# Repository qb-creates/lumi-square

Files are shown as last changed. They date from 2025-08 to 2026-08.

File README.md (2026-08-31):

# LumiSquare
LumiSquare is a handheld 4x4 LED button game console built around an ATSAMD21J18A. Each of the sixteen silicone pads sits on top of its own RGB LED, and a single 16-channel constant-current driver paints all forty-eight color channels through a column-multiplexed matrix. The console ships with three games, spoken score readout through a DFPlayer Mini, a tone buzzer for note feedback, and a USB-C rechargeable power path that lets the device be played while it charges.

- Project Video (YouTube): https://youtu.be/QTP0zEY1d-M?si=SdRo0hkOKRWzujol
- Multiplexed Display: https://en.wikipedia.org/wiki/Multiplexed_display
- Keyboard Matrix Circuit (diode anti-ghosting): https://en.wikipedia.org/wiki/Keyboard_matrix_circuit
- STP16CPC05 Constant Current LED Driver: https://www.st.com/en/power-management/stp16cpc05.html
- DFPlayer Mini Documentation: https://wiki.dfrobot.com/DFPlayer_Mini_SKU_DFR0299

<div align="center">
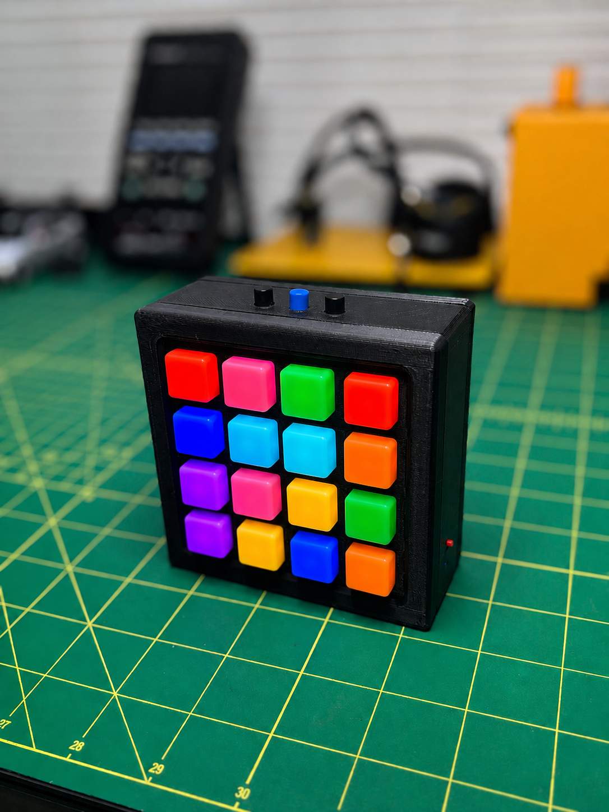
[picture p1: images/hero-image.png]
LumiSquare
	
</div>

## Table of Contents
1. [Software Used](#software)
2. [Main Control Board Circuit](#maincontrolboard)
    - [Power Path and Battery Charging](#powerpath)
    - [LED Button Matrix Driver](#leddriver)
    - [Button Matrix Circuit](#buttonmatrixcircuit)
    - [Buzzer Control](#buzzercontrol)
    - [DF Player Mini](#dfplayer)
    - [Game Firmware](#gamefirmware)
        - [Simon](#simon)
        - [Memory Matching](#memorymatching)
        - [Light Dash](#lightdash)
    - [Power Consumption](#powerconsumption)
    - [Charging Notes](#charging)
    - [Parts List](#partslist)
    - [Schematics](#schematics)
    - [PCB Images](#pcbimages)
3. [Pin Mapping](#pinmapping)
    - [DF Player Mini](#dfplayerpins)
    - [Buzzer](#buzzerpins)
    - [LED Mapping](#ledmapping)
    - [4x4 Button Mapping](#buttonmapping)
4. [STL Viewer](#stlviewer)
    - [Full Design](#fulldesign)
    - [Face Plate](#faceplate)
    - [Back Cover](#backcover)
    - [Main Body](#mainbody)
    - [Main Control Board](#maincontrolboardstl)

## 1. Software Used
- VSCode: https://code.visualstudio.com
- OpenOCD (Arm GDB Bridge): https://openocd.org/pages/about.html
- Arm GNU Toolchain (programming and debugging): https://developer.arm.com/tools-and-software/gnu-toolchain
- KiCad (PCB Design): https://www.kicad.org
- Autodesk Fusion (Parts Design): https://www.autodesk.com/products/fusion-360/overview

The firmware is a CMake project with two presets. `cmake_generate_debug` / `cmake_build_debug` cross compile for the SAMD21 with `arm-none-eabi-gcc` (Cortex-M0+, `F_CPU=48000000`) and emit an `.elf`, `.hex`, and `.bin`. `cmake_generate_desktop` / `cmake_build_desktop` build the same game code as a desktop executable with `DESKTOP_SIMULATION` defined, which swaps the SAMD21 hardware layer for an ImGui/GLFW/miniaudio implementation so the games, LED colors, and audio can be developed without the board. Flashing and debugging is done over the Samtec FTSH-105 SWD header using OpenOCD as the GDB bridge for `arm-none-eabi-gdb`.

## 2. Main Control Board Circuit
The main control board carries everything except the switches and LEDs themselves: the USB-C charger, the battery power path, both boost converters, the 3.3 V regulator, the SAMD21, the LED driver and its column drivers, the tone buzzer, and the DFPlayer Mini. It connects to the button matrix board through two 12-pin headers, one carrying the twelve LED cathode channels and one carrying the four button rows, four button columns, and four LED column anodes.

<div align="center">
 <table>
     <tr>
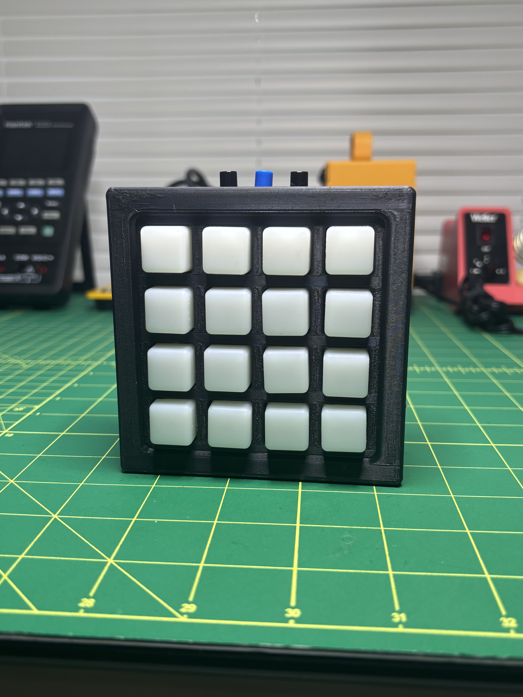
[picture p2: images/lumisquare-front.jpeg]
LumiSquare Front
         <td></td>
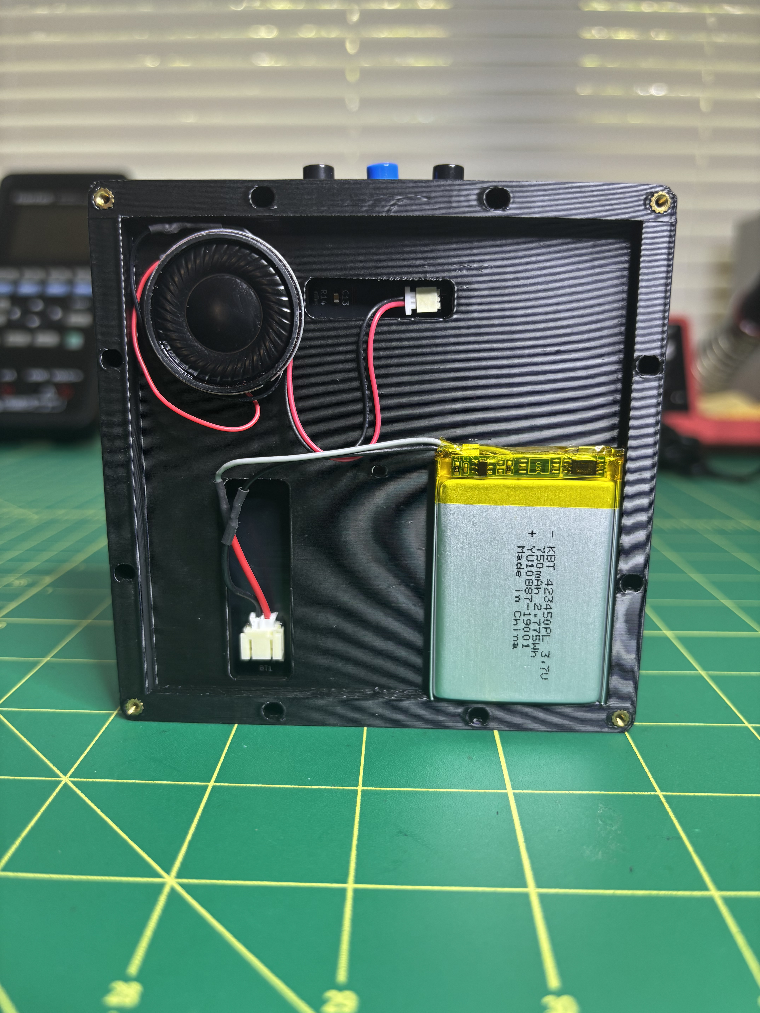
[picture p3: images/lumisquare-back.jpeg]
LumiSquare Back
         <td></td>
     </tr>
     <tr>
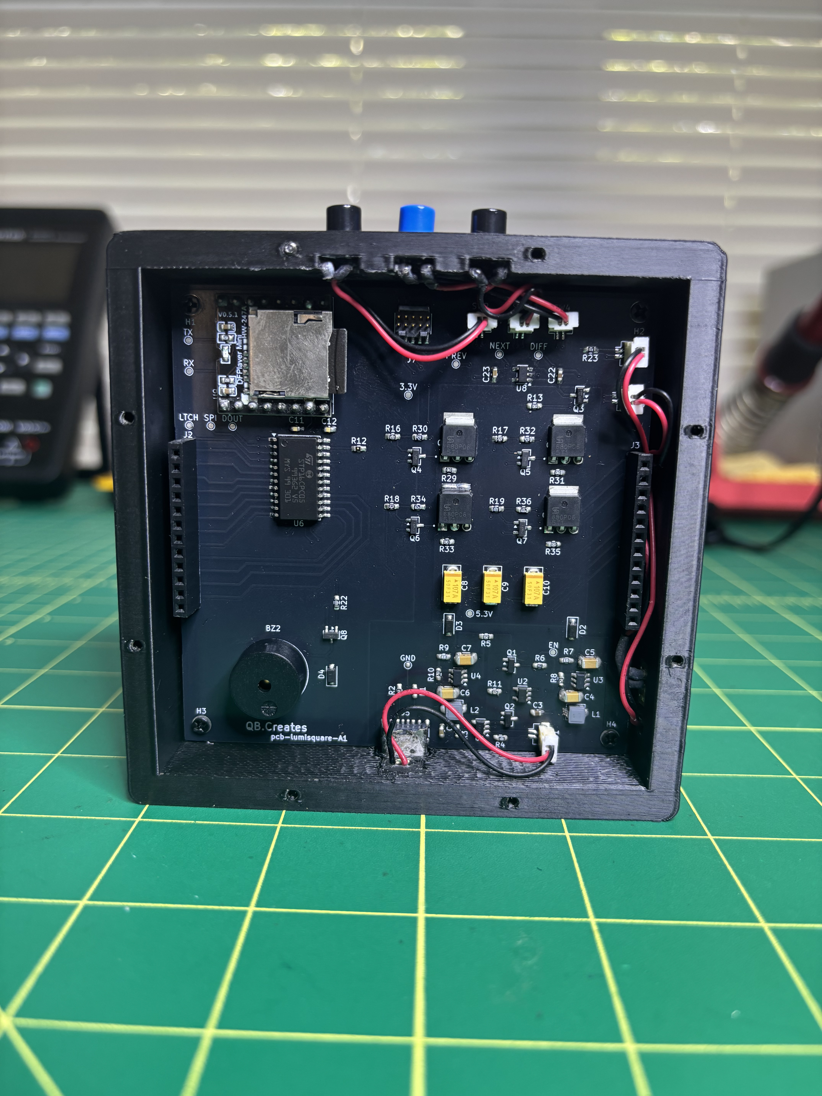
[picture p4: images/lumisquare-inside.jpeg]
LumiSquare Inside
         <td></td>
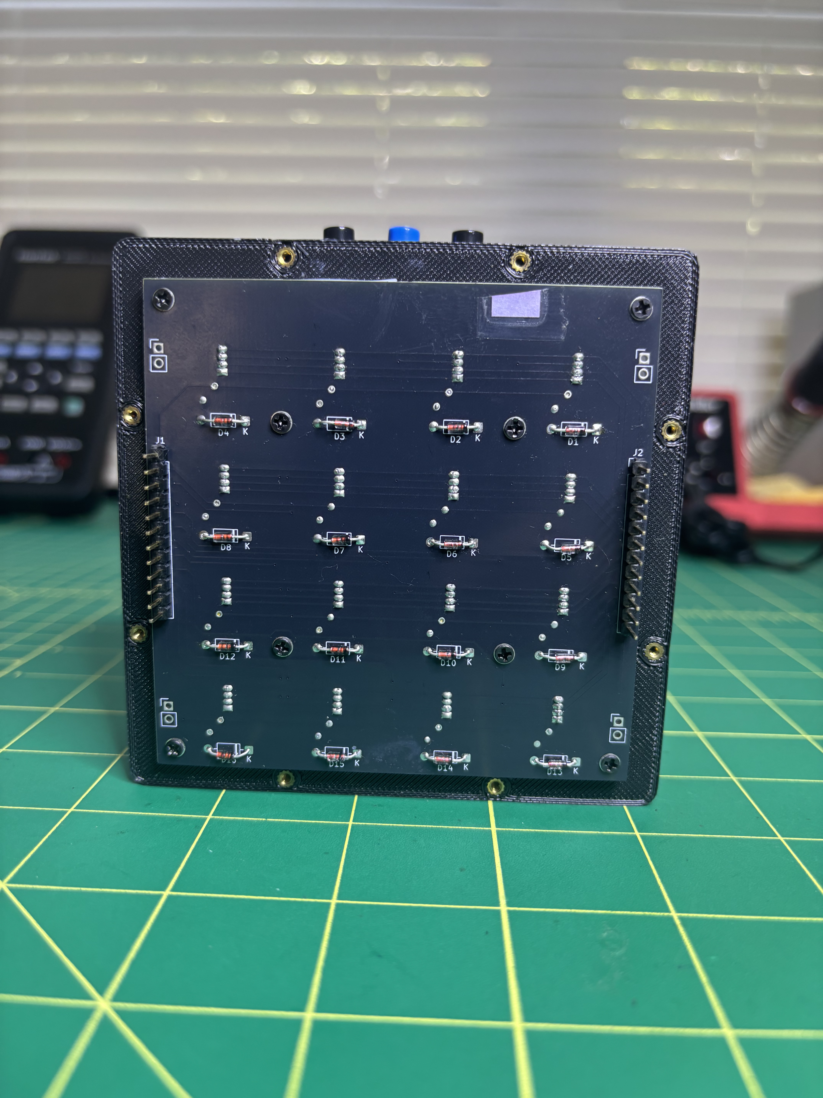
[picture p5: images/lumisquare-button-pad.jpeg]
LumiSquare Button Pad
         <td></td>
     </tr>
 </table>
</div>

### Power Path and Battery Charging
The board runs from either a single cell LiPo or USB-C, and the two sources are kept electrically separate so the device can be used while it charges.

Charging is handled by an MCP73831-2-OT (U1) off the USB-C VBUS rail. The USB-C receptacle is a power-only 6-pin part with the two 5.1k CC pulldowns (R1, R2) needed to advertise a sink. The charge current is set by the PROG resistor:

- Charge current = 1000 V / R3 = 1000 V / 10 kohm = 100 mA

A status LED (D1) with a 330 ohm series resistor (R4) is driven from the STAT pin.

The power path itself is built from two TLV61070A boost converters and a P-channel pass device:

- Q2 (IRLML2246) sits between the battery and the battery-side boost converter. Its gate is tied to the 5 V USB rail and pulled to ground through R11 (220k). With no USB present the gate sits at 0 V and the MOSFET conducts; when USB is plugged in the gate is pulled to 5 V and the battery is disconnected from the system load.
- U3 (TLV61070A) is the battery boost converter. Its enable pin is pulled up to the battery through R6 (150k) and is gated two ways: a TPS3840 (U2) supervisor pulls it low on battery undervoltage, and Q1 (IRLML6244) pulls it low whenever the 5 V USB rail is present.
- U4 (TLV61070A) is the USB boost converter. Its enable pin is tied to its own input, so it runs whenever USB power is present.
- Both converters use a 4.7uH inductor and the same 720k/80k feedback divider, and their outputs are combined onto the 5.3 V rail through Schottky diodes (D2, D3, 1N5819HW-7-F) with 300uF of bulk capacitance (C8, C9, C10).

Downstream of the 5.3 V rail, SW1 is the system power switch feeding a MIC5225-3.3YM5 (U8) that produces the +3.3 V Main rail for the SAMD21, the DFPlayer Mini, and the buzzer. The 5.3 V rail itself powers the LED column drivers, so the RGB LEDs get their headroom from the boost output rather than the regulated logic rail.

### LED Button Matrix Driver
Sixteen common-anode RGB LEDs are driven as a 4x4 multiplexed matrix. Anodes are shared per column, and cathodes are shared per row and color, which reduces forty-eight LED channels down to twelve driver channels plus four column selects.

The cathode side is an STP16CPC05MTR (U6) constant-current sink. Twelve of its sixteen channels are used, one for each row and color combination, and a 200 ohm resistor (R12) on R-EXT sets the per-channel current for all of them. The MCU talks to it over SERCOM4 in SPI master mode (MSB first, 16 bits per update), with a separate GPIO line used to pulse the latch.

The anode side is a high-side switch per column. Each column select from the MCU drives an MMBT3904 (Q4-Q7) through a 2.2k base resistor with a 47k pulldown; the transistor pulls the gate of a TSM680P06CH P-channel MOSFET (Q15-Q18) down against a 100k pullup to the 5.3 V rail, and the MOSFET drain feeds that column's anode line.

Color depth comes from binary code modulation rather than a per-channel PWM peripheral. Each LED stores its color as eight bit planes in `ledColorData[column][row][plane]`. `refreshLeds()` services one LED per call: it enables that LED's column, then shifts out all eight planes back to back, holding plane *i* for 2^i NOP loops so the planes carry the same weighting as the bits of an 8-bit value. After the last plane the driver is cleared to `0x0000` and the next LED index is selected. Only one column ever sources current at a time, and the sixteen LED slots repeat fast enough that the display looks continuous.

Per-LED intensity is a scale from 0 to 1 applied to the color before the bit planes are rebuilt, so the games can dim a pad (the idle Simon pads sit at 0.2 intensity, for example) without changing its color.

### Button Matrix Circuit
The button matrix board holds the sixteen switches, the sixteen RGB LEDs, and nothing else. Switches are wired as a standard 4x4 matrix with a 1N4148 diode in series with every switch (D1-D16) so that simultaneous presses cannot ghost onto unrelated rows. The MCU drives one column low at a time and reads the four row inputs, which are held high by internal pullups, so a pressed button reads as a logic low on its row while its column is active.

The LEDs on this board are wired to match. Anodes are commoned per column (LED_COL1 through LED_COL4) and cathodes are commoned per row and color (LED_R1/G1/B1 through LED_R4/G4/B4). Both groups leave the board on 12-pin headers that mate with the main control board.

**Assembly notes for the button pad:**

- The 4x4 silicone button pad in the parts list is not the right size for this enclosure. The individual pads have to be cut out of the sheet and placed into the pockets in the face plate.
- If you have the button matrix board fabricated, order it with an immersion gold (ENIG) finish. The exposed contact pads need a gold surface for the conductive pill on the bottom of each silicone button to make reliable contact.
- If the board is made with a plain finish instead, buy the copper tape listed in the parts list and adhere a piece to the bottom of each button pad so that the button can bridge the traces.

### Buzzer Control
Tones are produced by a magnetic transducer (BZ2, RDT-4.000-1375-NS1) switched on the low side by an MMBT3904 (Q8). The base is driven through a 2.2k resistor (R22) from the MCU, and a 1N4148W (D4) across the transducer clamps the inductive kickback back into the +3.3 V rail.

The drive signal is hardware PWM from TC7 on PB23. TC7 runs from the 48 MHz main clock with a divide-by-256 prescaler in match PWM mode:

- Timer clock = 48 MHz / 256 = 187.5 kHz
- Output frequency = 187500 / (CC0 + 1)
- `CC1` is always set to `CC0 / 2`, which holds the duty cycle at 50 percent regardless of pitch

Because the period register alone determines pitch, the `MusicNote` enum stores CC0 values directly instead of frequencies. For example `MusicNote::C4 = 716`, which gives 187500 / 717 = 261.5 Hz. Starting and stopping a note is just enabling or disabling the timer, so note timing stays exact while the game loop is busy elsewhere.

### DF Player Mini
Spoken audio comes from a DFPlayer Mini (DFR0299) running off the +3.3 V rail, with its speaker outputs broken out to a JST connector. The module is driven from SERCOM5 in USART mode on PA20/PA21 at 9600 baud.

Every DFPlayer command is a fixed 10-byte frame (`0x7E 0xFF 0x06 <cmd> 0x00 <param hi> <param lo> <checksum hi> <checksum lo> 0xEF`). Rather than building those frames at runtime, the firmware stores all of them precomputed in a constant table, so playing a clip is a table lookup. Frames are pushed out by DMAC channel 0 triggered off the SERCOM5 transmit event, one beat per trigger, so the game loop never blocks on the UART.

Replies come back through the SERCOM5 receive interrupt, which buffers the module's 20-byte response (the command acknowledgement plus the playback-finished frame) and fires a completion callback when the terminating `0xEF` arrives. That callback is what advances queued voice-over sequences, which is how the console reads a multi-digit score back as separate clips.

Audio content is organized into four folders on the SD card, and the command table plays from them by folder and track number:

| Folder | Contents |
|:--|:--|
| 01 | Digits 0 through 9 |
| 02 | 10 through 20, then 30, 40, 50, 60, 70, 80, 90 |
| 03 | 100, 200, 300, 400, 500 |
| 04 | Phrases: "your score is", "new high score", the game names, the difficulty names, countdown, mute, unmute |

To read a score such as 342, the firmware queues the hundreds clip, then the tens clip, then the ones clip, and lets the completion callback chain them together. Volume is set with command `0x06`; the unmute command sends a value of 25, and muting sends a value of 0.

### Game Firmware
The firmware is a fixed-timestep game engine. TC3 runs from the 48 MHz clock with a divide-by-1024 prescaler and is preloaded so it overflows every 16 ms, giving a 62.5 Hz update rate. The main loop looks like this:

```cpp
while (true)
{
    LEDMatrix::refreshLeds();

    if (!DeviceUtility::fixedUpdate)
        continue;

    DeviceUtility::fixedUpdate = false;
    Input::pollButtons();

    StateManager::Instance().onFixedUpdate();
    AudioSource::Instance().onFixedUpdate();
    ShutdownUtility::Instance().onFixedUpdate();
    SerialCommandManager::Instance().onFixedUpdate();
}
```

LED refresh runs as fast as the CPU allows, while everything else is gated on the 16 ms tick. All game timers are expressed in milliseconds and decremented by `DeviceUtility::DELTA_TIME`, so game speed is independent of how quickly the LED refresh happens to be running.

All hardware access goes through an abstract `DeviceUtility` singleton. `SAMD21J18Utility` implements it against the real peripherals, and `DesktopUtility` implements the same interface with ImGui, GLFW, and miniaudio. Every layer above it (games, LED matrix, input, audio, scoring) is shared between the two builds.

Game flow is a state machine. `StateManager` holds one instance of each state and dispatches `enterState`, `updateState`, `exitState`, and `onButtonPressed` to whichever one is current:

| State | Purpose |
|:--|:--|
| PowerOn | Startup animation and audio |
| Menu | Game selection, difficulty selection, mute toggle, start countdown |
| MemoryMatching | Color pair matching game |
| Simon | Sequence memorization game |
| LightDash | Timed reaction game |
| GameOver | Score readout and high score announcement |

In the menu, the Next and Previous buttons cycle through the three games and the Difficulty button cycles Easy, Medium, Hard. Holding the Difficulty button for one second toggles mute instead of changing difficulty, and the new mute state is announced through the DFPlayer. Selecting a game plays a spoken 3-2-1 countdown before the state switch.

`ScoreManager` tracks the current score and a high score per game and per difficulty in a 6x3 matrix. Persistence is handled by `StorageService`, which keeps high scores in the SAMD21's own flash instead of an external EEPROM. The linker script carves the last 1 KB of the 256 KB flash out of the `rom` region and gives it its own memory region:

```
rom      (rx)  : ORIGIN = 0x00000000, LENGTH = 0x0003FC00
eeprom   (rx)  : ORIGIN = 0x0003FC00, LENGTH = 0x00000400
```

A matching `.eeprom` output section is mapped into that region, and the high score array is placed there with `__attribute__((__section__(".eeprom")))`, so the linker will never let program code grow into the saved data. Each high score is a single byte addressed by game and difficulty: Memory Matching at offset 0, Simon at offset 6, Light Dash at offset 12, plus the difficulty index. A byte that has never been written reads back as `0xFF` and is reported as a score of zero.

Reading a high score is a direct pointer dereference into that flash region. Writing has to respect the SAMD21's flash granularity, so saving one byte means copying the surrounding 256-byte row into RAM, patching the byte, erasing the row through NVMCTRL, and writing all four 64-byte pages back. The read and write bodies are commented out in `StorageService` at the moment, so high scores currently live in RAM until they are re-enabled.

#### Simon
The console plays a growing sequence of lit pads with a distinct note per pad, and the player repeats it. Only eight of the sixteen pads are playable. On Easy the four center pads are used (indexes 5, 6, 9, 10); on Medium and Hard the four corners (0, 3, 12, 15) are added. Each playable pad has a fixed note assignment:

| Pad Index | Note | Pad Index | Note |
|:--:|:--:|:--:|:--:|
| 5 | G4 | 4 | A4 |
| 6 | C4 | 7 | D4 |
| 9 | E4 | 8 | F4 |
| 10 | G3 | 11 | B3 |

The player gets three lives on Easy and Medium and a single life on Hard. Idle pads sit at 0.2 intensity and the active pad steps up to full intensity for each sequence element, so the sequence reads clearly without the board going dark between steps.

#### Memory Matching
Eight color pairs are shuffled across the sixteen pads at the start of the round. Pressing a pad lights it in its hidden color; pressing a second pad evaluates the guess. Matched pairs stay lit, mismatched pads fade back off after a short reveal timer, and the round ends once all eight matches are found. Selection and evaluation are confirmed with C5 and D5 tones.

#### Light Dash
A 30 second timed reaction round. Five pads start lit in turquoise, and every lit pad carries its own randomized turn-off timer. Hitting a lit pad scores a point and immediately lights a new random pad; hitting a dark pad deducts points and plays a low B3. Difficulty changes the pressure directly:

| Difficulty | LED Turn-Off Window | Score Deduction | Bonus Pad Value | Bonus Window | Power-Ups |
|:--|:--:|:--:|:--:|:--:|:--:|
| Easy | 1500 - 2500 ms | -1 | 5 | 400 ms | Disabled |
| Medium | 1000 - 2000 ms | -2 | 3 | 500 ms | Enabled |
| Hard | 750 - 1200 ms | -3 | 5 | 400 ms | Enabled |

### Power Consumption
This power system was sized around continuous play with the LED matrix, the DFPlayer Mini, and the buzzer all active, measured on the finished assembly rather than estimated from datasheet maximums.

Measured load envelope:

- USB input, playing while charging: ~170 mA typical, 200 mA maximum
- Battery draw with USB disconnected: ~100 mA typical, 120 mA maximum
- Programmed battery charge current (MCP73831 with a 10k PROG resistor): 100 mA

The USB figure is the total of both jobs at once: the system load through the USB boost converter plus the 100 mA going into the battery. Against the 500 mA available from a standard USB port:

- Worst-case USB draw: 0.20 A of the 0.50 A available
- Remaining headroom: 0.30 A, roughly 40 percent port utilization

Battery capability and runtime with a 750 mAh single cell LiPo:

- Typical: 750 mAh / 100 mA = 7.5 h
- Worst case: 750 mAh / 120 mA = 6.25 h

That works out to roughly 6 to 7.5 hours of continuous play per charge, with the practical number landing near the low end of that range because the boost converter draws more input current as the cell voltage falls toward its cutoff. A full recharge from empty at 100 mA takes about 8 hours once the constant-voltage taper at the end of the charge cycle is included.

Conclusion: the USB port has roughly 300 mA of unused headroom even in the worst case, so charging and full-brightness play can happen at the same time without exceeding what a standard port supplies.

### Charging Notes
The device can be safely used while charging due to its power-path design. When USB power is connected, the battery-powered boost converter is disabled and the battery is isolated from the system load, allowing it to charge independently at 100 mA. The system is powered through a separate boost converter from USB power during this time. Since the combined system load and charging current remain well below the 500 mA available from a standard USB port, normal operation can continue while the battery is charging.

---
### Parts List
<div align="center">
    <table>
        <tr>
            <td valign="top">
                <table>
                    <tr><th>Part Number</th><th>Quantity</th></tr>
                    <tr><td><a href="https://www.amazon.com/dp/B0B21B262L?ref=ppx_yo2ov_dt_b_fed_asin_title&amp;th=1">4.2V Lipo</a></td><td align="center">x1</td></tr>
                    <tr><td><a href="https://www.digikey.com/en/products/detail/jst-sales-america-inc/S2B-PH-SM4-TB/926655">S2B-PH-SM4-TB</a></td><td align="center">x1</td></tr>
                    <tr><td><a href="https://www.digikey.com/en/products/detail/raltron-electronics/RDT-4-000-1375-NS1/22320849">RDT-4.000-1375-NS1</a></td><td align="center">x1</td></tr>
                    <tr><td><a href="https://www.digikey.com/en/products/detail/samsung-electro-mechanics/CL10A475KP8NNNC/3886702">4.7uF Capacitor</a></td><td align="center">x2</td></tr>
                    <tr><td><a href="https://www.digikey.com/en/products/detail/kyocera-avx/TPCL105M010R5000/1472496">1uF Tantalum Capacitor</a></td><td align="center">x3</td></tr>
                    <tr><td><a href="https://www.digikey.com/en/products/detail/taiyo-yuden/TMK107B7105KA-T/2714162">1uF Capacitor</a></td><td align="center">x2</td></tr>
                    <tr><td><a href="https://www.digikey.com/en/products/detail/murata-electronics/GCM31CR71C106KA64K/2592432">10uF Capacitor</a></td><td align="center">x2</td></tr>
                    <tr><td><a href="https://www.digikey.com/en/products/detail/murata-electronics/GCM31CR70J226ME23L/2592428">22uF Capacitor</a></td><td align="center">x2</td></tr>
                    <tr><td><a href="https://www.digikey.com/en/products/detail/kyocera-avx/TAJC107K010RNJ/563809">100uF Capacitor</a></td><td align="center">x3</td></tr>
                    <tr><td><a href="https://www.digikey.com/en/products/detail/kemet/C0603C102K5RACTU/411081">.001uF Capacitor</a></td><td align="center">x1</td></tr>
                    <tr><td><a href="https://www.digikey.com/en/products/detail/kemet/C0603C103K5RACTU/411090">.01uF Capacitor</a></td><td align="center">x1</td></tr>
                    <tr><td><a href="https://www.digikey.com/en/products/detail/kemet/C0603C104K3RACTU/416044">.1uF Capacitor</a></td><td align="center">x6</td></tr>
                    <tr><td><a href="https://www.digikey.com/en/products/detail/murata-electronics/GRM188R61E225KA12D/4905349">2.2uF Capacitor</a></td><td align="center">x1</td></tr>
                    <tr><td>LED</td><td align="center">x2</td></tr>
                    <tr><td><a href="https://www.digikey.com/en/products/detail/diodes-incorporated/1N5819HW-7-F/814970">1N5819HW-7-F Diode</a></td><td align="center">x2</td></tr>
                    <tr><td><a href="https://www.digikey.com/en/products/detail/smc-diode-solutions/1N4148W/6022450">1N4148W Diode</a></td><td align="center">x1</td></tr>
                    <tr><td><a href="https://www.amazon.com/2-54mm-Breakaway-Female-Connector-Arduino/dp/B01MQ48T2V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">Conn_01x12</a></td><td align="center">x2</td></tr>
                    <tr><td><a href="https://www.digikey.com/en/products/detail/gct/USB4125-GF-A/13547388">USB_C_Receptacle_PowerOnly_6P</a></td><td align="center">x1</td></tr>
                    <tr><td><a href="https://www.digikey.com/en/products/detail/samtec-inc/FTSH-105-01-L-DV-K/1875039">FTSH-105-01-X-DV-P-K-X</a></td><td align="center">x1</td></tr>
                    <tr><td><a href="https://www.digikey.com/en/products/detail/bourns-inc/SRP3020TA-4R7M/9350997">4.7uH</a></td><td align="center">x2</td></tr>
                    <tr><td><a href="https://www.digikey.com/en/products/detail/infineon-technologies/IRLML6244TRPBF/2393871">IRLML6244</a></td><td align="center">x1</td></tr>
                    <tr><td><a href="https://www.digikey.com/en/products/detail/umw/UMWIRLML2246TR/24889419">UMWIRLML2246TRCT</a></td><td align="center">x2</td></tr>
                    <tr><td><a href="https://www.digikey.com/en/products/detail/onsemi/MMBT3904LT1G/919601">MMBT3904</a></td><td align="center">x5</td></tr>
                    <tr><td><a href="https://www.digikey.com/en/products/detail/taiwan-semiconductor-corporation/TSM680P06CH-X0G/7360503">TSM680P06CH</a></td><td align="center">x4</td></tr>
                    <tr><td><a href="https://www.digikey.com/en/products/detail/yageo/RC0603FR-075K1L/727268">5.1k ohm Resistor</a></td><td align="center">x2</td></tr>
                    <tr><td><a href="https://www.digikey.com/en/products/detail/stackpole-electronics-inc/RMCF0603JT10K0/1758104">10k ohm Resistor</a></td><td align="center">x2</td></tr>
                    <tr><td><a href="https://www.digikey.com/en/products/detail/yageo/RC0603FR-07330RL/727162">330 ohm Resistor</a></td><td align="center">x2</td></tr>
                    <tr><td><a href="https://www.digikey.com/en/products/detail/yageo/RC0603JR-071K3L/726686">1.3k ohm Resistor</a></td><td align="center">x1</td></tr>
                    <tr><td><a href="https://www.digikey.com/en/products/detail/koa-speer-electronics-inc/RK73B1JTTD154J/9844780">150k ohm Resistor</a></td><td align="center">x1</td></tr>
                </table>
            </td>
            <td width="24"></td>
            <td valign="top">
                <table>
                    <tr><th>Part Number</th><th>Quantity</th></tr>
                    <tr><td><a href="https://www.digikey.com/en/products/detail/yageo/RC0603FR-07715KL/727372">720k ohm Resistor</a></td><td align="center">x2</td></tr>
                    <tr><td><a href="https://www.digikey.com/en/products/detail/yageo/RC0603JR-0775KL/726828">80k ohm Resistor</a></td><td align="center">x2</td></tr>
                    <tr><td><a href="https://www.digikey.com/en/products/detail/stackpole-electronics-inc/RMCF0603FT220K/1760805">220k ohm Resistor</a></td><td align="center">x1</td></tr>
                    <tr><td><a href="https://www.digikey.com/en/products/detail/rohm-semiconductor/ESR03EZPF2000/1983436">200 ohm Resistor</a></td><td align="center">x1</td></tr>
                    <tr><td><a href="https://www.digikey.com/en/products/detail/yageo/RC0603FR-07100KL/726889">100k ohm Resistor</a></td><td align="center">x5</td></tr>
                    <tr><td><a href="https://www.digikey.com/en/products/detail/panasonic-industry/ERA-3AEB153V/1465882">15k ohm Resistor</a></td><td align="center">x3</td></tr>
                    <tr><td><a href="https://www.digikey.com/en/products/detail/yageo/RC0603FR-072K2L/727016">2.2k ohm Resistor</a></td><td align="center">x5</td></tr>
                    <tr><td><a href="https://www.digikey.com/en/products/detail/yageo/RC0603FR-0747KL/727253">47k ohm Resistor</a></td><td align="center">x4</td></tr>
                    <tr><td><a href="https://www.amazon.com/2-54mm-Breakaway-Female-Connector-Arduino/dp/B01MQ48T2V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">SW_SPST</a></td><td align="center">x1</td></tr>
                    <tr><td><a href="https://www.digikey.com/en/products/detail/jst-sales-america-inc/SM02B-NSHSS-TB/3313627">SM02B-NSHSS-TB</a></td><td align="center">x1</td></tr>
                    <tr><td><a href="https://www.amazon.com/dp/B0FD32HBD2?ref=ppx_yo2ov_dt_b_fed_asin_title">JST SH 1.0mm 2-Pin Connector Male</a></td><td align="center">x6</td></tr>
                    <tr><td><a href="https://www.digikey.com/en/products/detail/jst-sales-america-inc/BM02B-SRSS-TB/926694">455-1788-1-ND</a></td><td align="center">x6</td></tr>
                    <tr><td><a href="https://www.digikey.com/en/products/detail/e-switch/TL3342F260QG/4029402">TL3342F260QG</a></td><td align="center">x1</td></tr>
                    <tr><td><a href="https://www.amazon.com/dp/B07FS9CLHB?ref=ppx_yo2ov_dt_b_fed_asin_title">SW_Push</a></td><td align="center">x3</td></tr>
                    <tr><td><a href="https://www.digikey.com/en/products/detail/microchip-technology/MCP73831T-4ADI-OT/1874437">MCP73831-2-OT</a></td><td align="center">x1</td></tr>
                    <tr><td><a href="https://www.digikey.com/en/products/detail/texas-instruments/TPS3840DL35DBVR/15857118">TPS3840</a></td><td align="center">x1</td></tr>
                    <tr><td><a href="https://www.digikey.com/en/products/detail/texas-instruments/TLV61070ADBVR/16982069">TLV61070A</a></td><td align="center">x2</td></tr>
                    <tr><td><a href="https://www.digikey.com/en/products/detail/microchip-technology/ATSAMD21J18A-AUT/4878863">ATSAMD21J18A-A</a></td><td align="center">x1</td></tr>
                    <tr><td><a href="https://www.digikey.com/en/products/detail/stmicroelectronics/STP16CPC05MTR/2021162">STP16CPC05MTR</a></td><td align="center">x1</td></tr>
                    <tr><td><a href="https://www.digikey.com/en/products/detail/microchip-technology/MIC5225-3-3YM5-TR/1815447">MIC5225-3.3YM5</a></td><td align="center">x1</td></tr>
                    <tr><td><a href="https://www.amazon.com/dp/B09YGDQV3Z?ref=ppx_yo2ov_dt_b_fed_asin_title&amp;th=1">Speaker</a></td><td align="center">x1</td></tr>
                    <tr><td><a href="https://www.amazon.com/HiLetgo-Arduino-Player-Module-DFPlayer/dp/B01D1D0E7Q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">DFPLayerMini</a></td><td align="center">x1</td></tr>
                    <tr><td><a href="https://www.sparkfun.com/button-pad-4x4-led-compatible.html">Button Pad</a></td><td align="center">x1</td></tr>
                    <tr><td><a href="https://www.amazon.com/Tricolor-Multicolor-Lighting-Electronics-Components/dp/B01C19ENFK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">RGB leds</a></td><td align="center">x16</td></tr>
                    <tr><td><a href="https://www.amazon.com/2-54mm-Breakaway-Female-Connector-Arduino/dp/B01MQ48T2V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">Conn_01x12</a></td><td align="center">x16</td></tr>
                    <tr><td><a href="https://www.amazon.com/ruthex-Threaded-Insert-pieces-ultrasound/dp/B088QJG676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">M2x4 Inserts</a></td><td align="center">x2</td></tr>
                    <tr><td><a href="https://www.amazon.com/Phillips-Countersunk-Electronic-Accessories-Samsung/dp/B07HC3LQYS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">m2 scews</a></td><td align="center">x24</td></tr>
                    <tr><td><a href="https://www.amazon.com/Kirecoo-Conductive-Shielding-Electrical-Grounding/dp/B09Z6F9RFG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">copper tape</a></td><td align="center">x24</td></tr>
                </table>
            </td>
        </tr>
    </table>
</div>

### Schematics
#### Main Control Board Schematic
<div align="center">
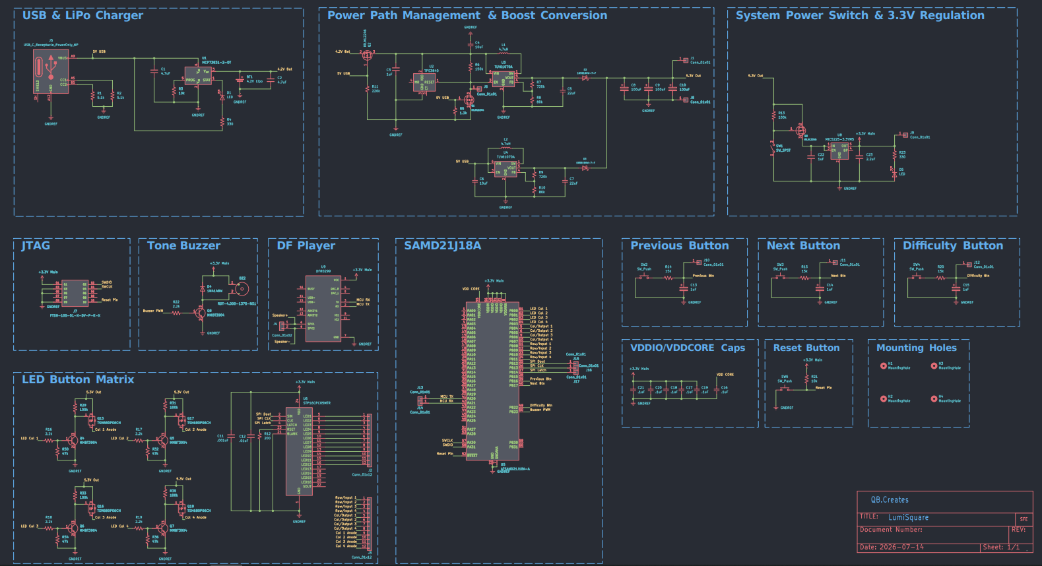
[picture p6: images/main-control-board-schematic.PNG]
Main Control Board Schematic
    
</div>

#### Button Matrix Schematic
<div align="center">
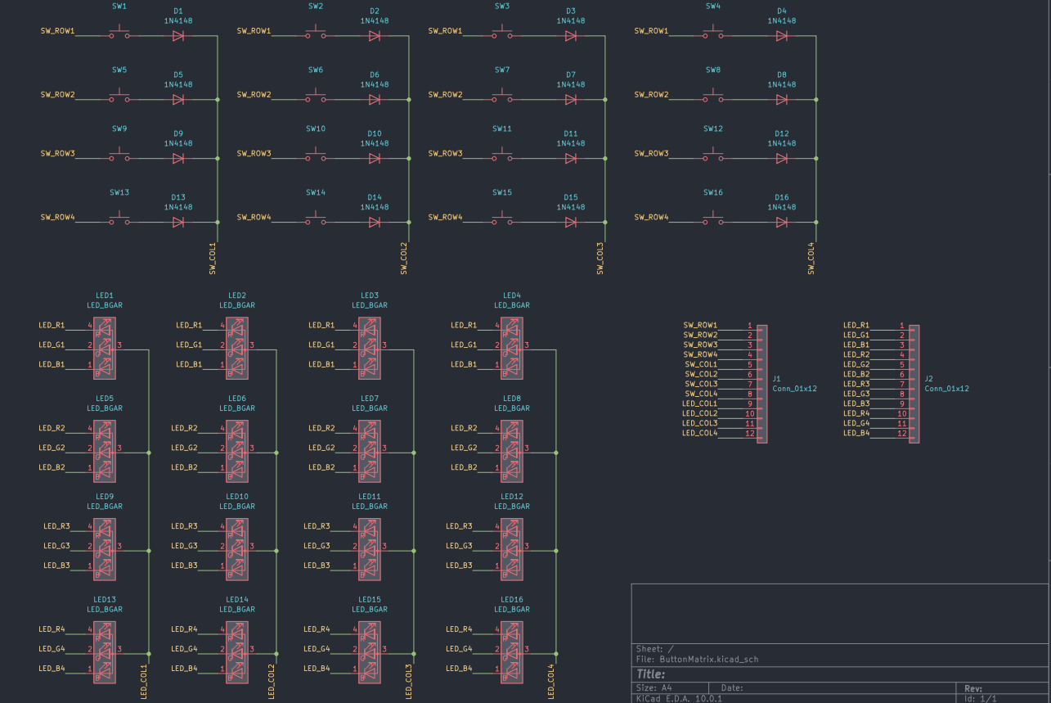
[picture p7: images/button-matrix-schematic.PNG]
Button Matrix Schematic
    
</div>

### PCB Images
#### Main Control Board
<div align="center">
 <table>
     <tr>
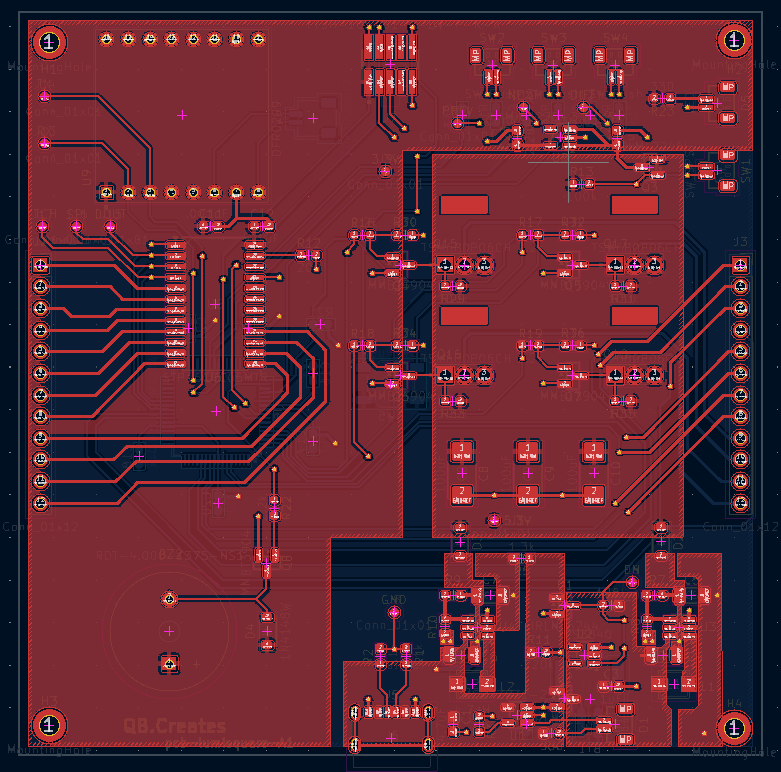
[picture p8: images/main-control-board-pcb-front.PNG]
Main Control Board PCB Front
         <td></td>
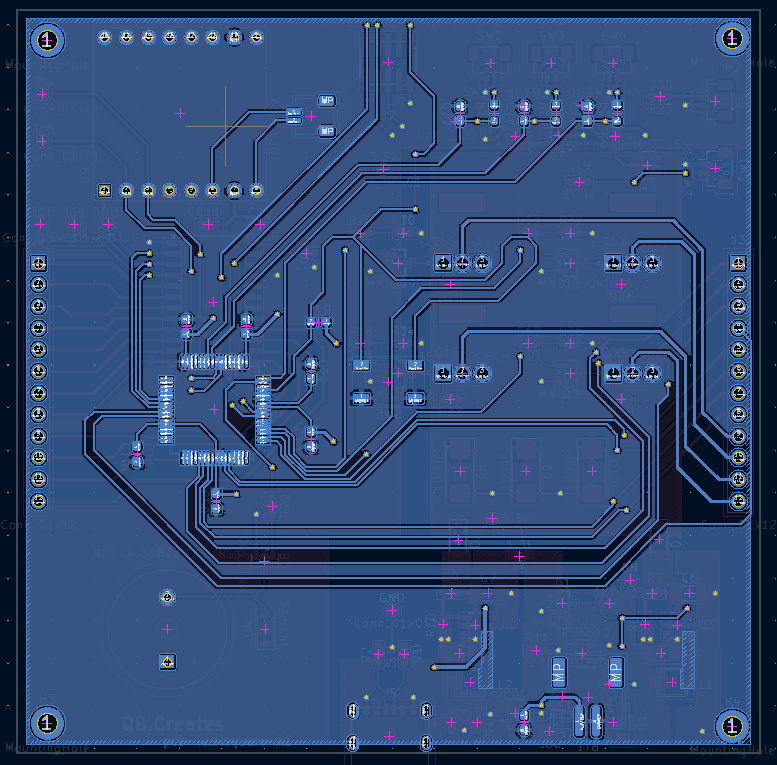
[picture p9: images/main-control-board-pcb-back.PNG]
Main Control Board PCB Back
         <td></td>
     </tr>
     <tr>
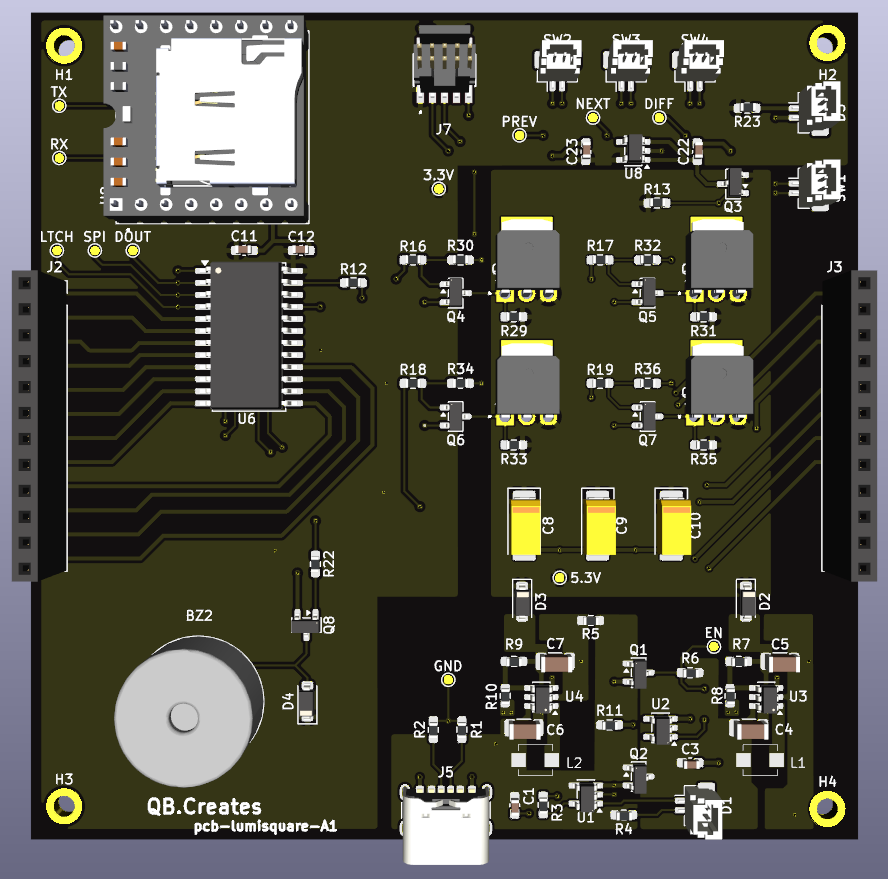
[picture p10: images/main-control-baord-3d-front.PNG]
Main Control Board 3D Front
         <td></td>
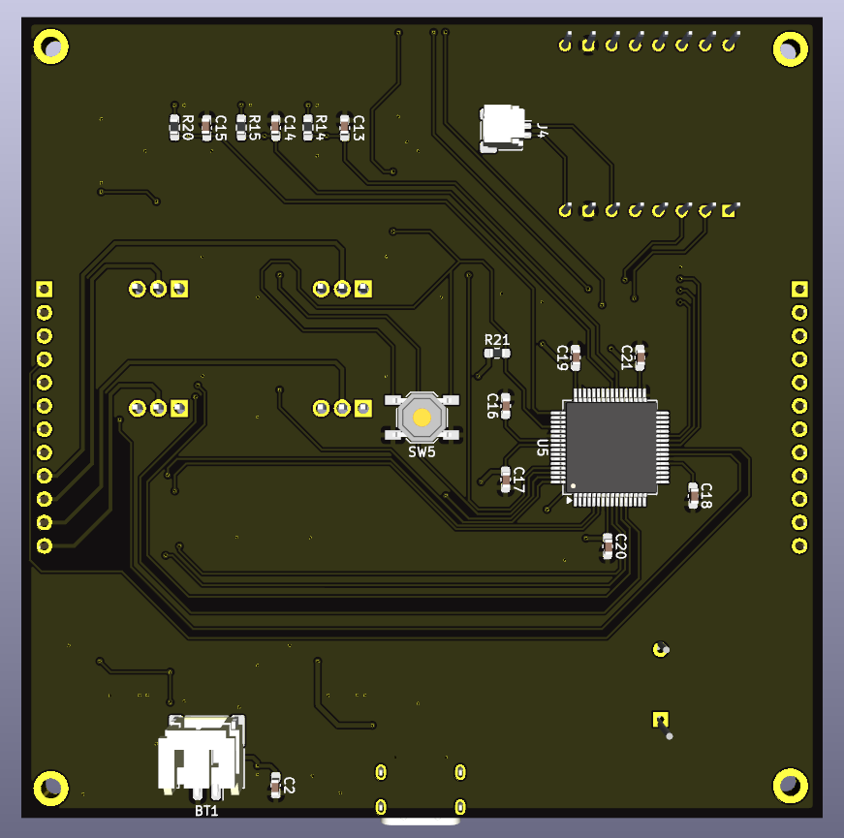
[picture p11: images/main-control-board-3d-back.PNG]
Main Control Board 3D Back
         <td></td>
     </tr>
 </table>
</div>

#### Button Matrix
<div align="center">
 <table>
     <tr>
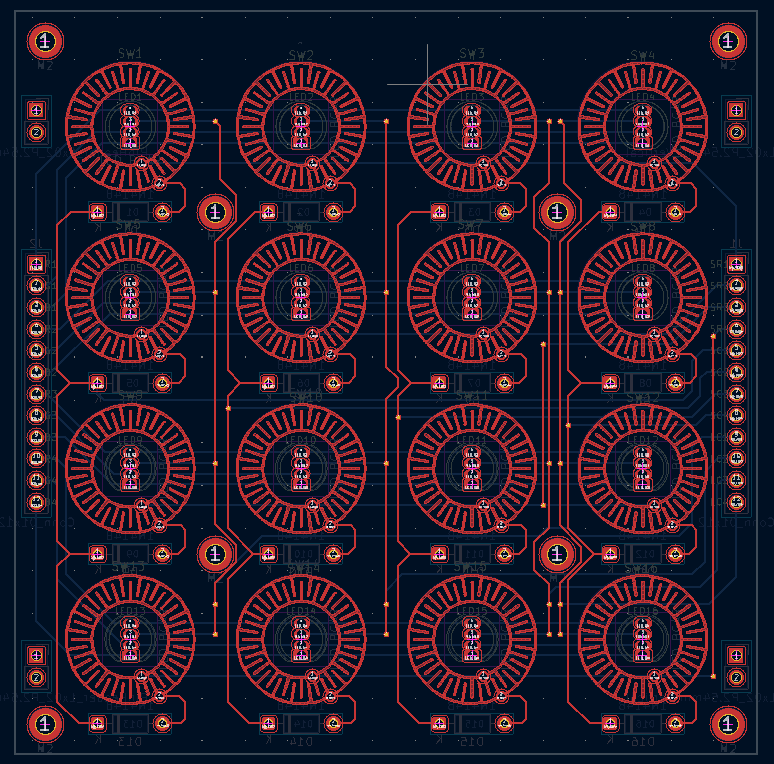
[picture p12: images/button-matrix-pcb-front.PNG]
Button Matrix PCB Front
         <td></td>
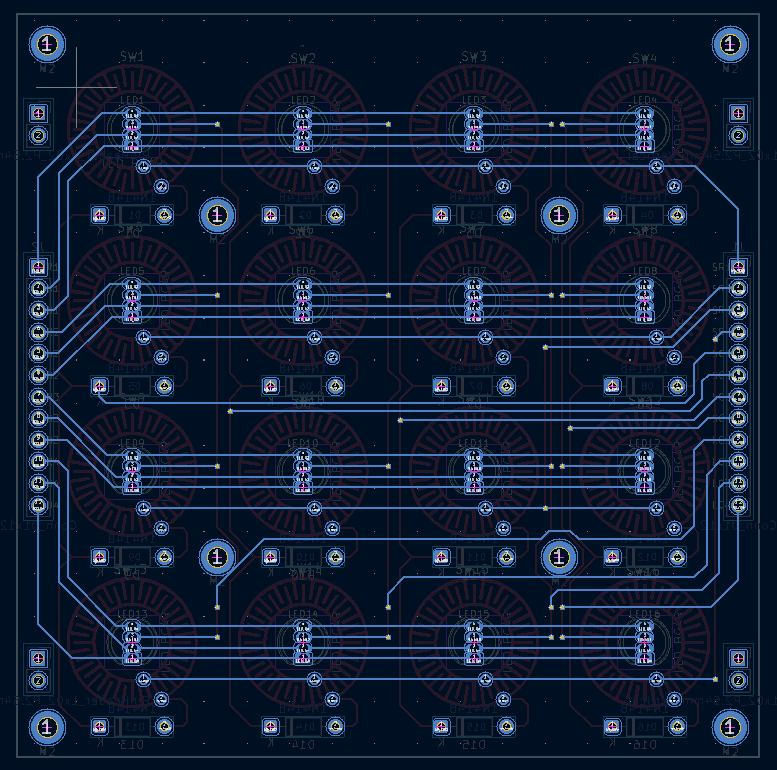
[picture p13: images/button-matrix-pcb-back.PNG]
Button Matrix PCB Back
         <td></td>
     </tr>
     <tr>
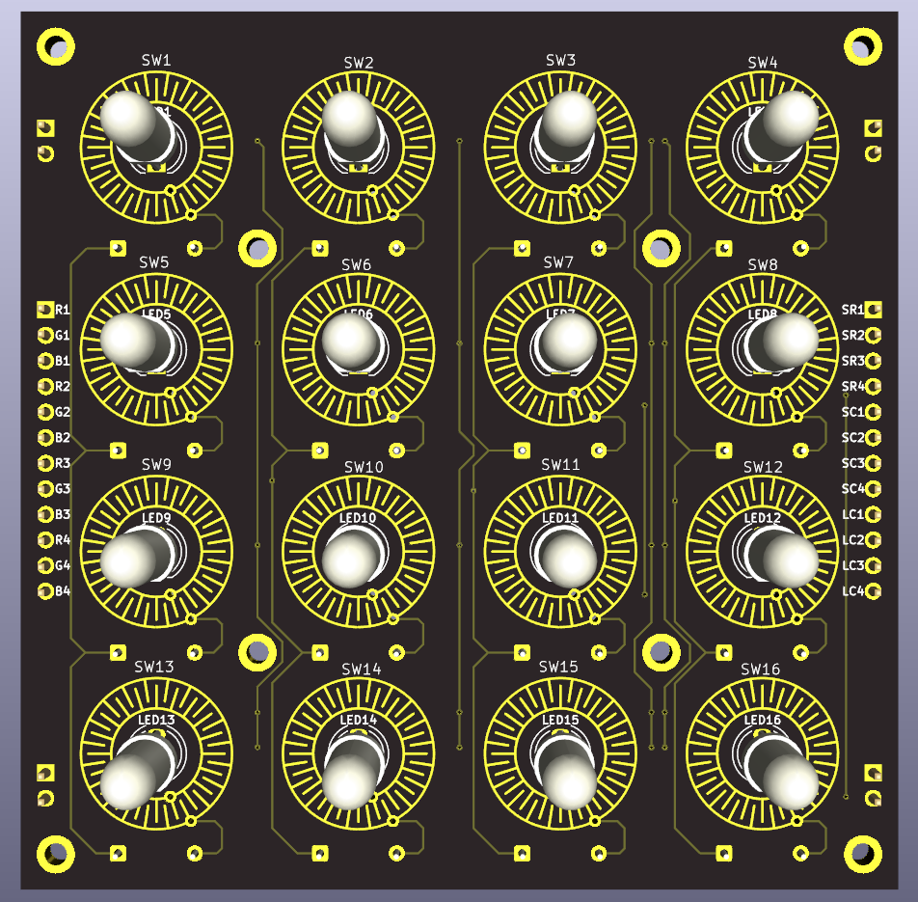
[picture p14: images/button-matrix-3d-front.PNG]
Button Matrix 3D Front
         <td></td>
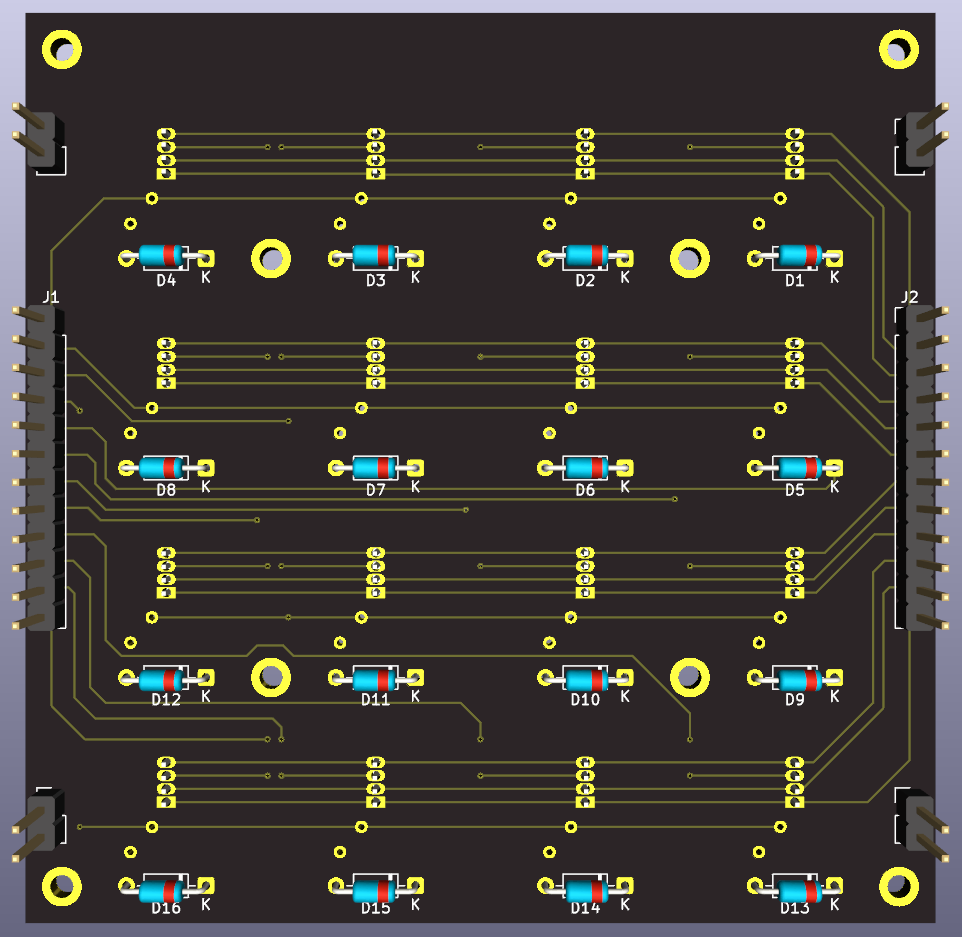
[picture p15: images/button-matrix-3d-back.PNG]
Button Matrix 3D Back
         <td></td>
     </tr>
 </table>
</div>

## 3. Pin Mapping 
ATSAMD21J18A pin information is from the Microchip product page and datasheet: https://www.microchip.com/en-us/product/ATSAMD21J18A

### DF Player Mini
| Signal | MCU Pin | DFPlayer Pin | Notes |
|:--|:--|:--|:--|
| USART TX | PA20 | RX (pin 2) | SERCOM5 USART at 9600 baud. 10-byte command frames are pushed out by DMAC channel 0 |
| USART RX | PA21 | TX (pin 3) | SERCOM5 receive interrupt buffers the 20-byte reply and fires the playback completion callback |
| VCC | - | VCC (pin 1) | +3.3 V Main rail |
| GND | - | GND (pin 7) | |
| Speaker + | - | SPK1 (pin 6) | Routed to the J4 JST speaker connector |
| Speaker - | - | SPK2 (pin 8) | Routed to the J4 JST speaker connector |

### Buzzer
| Signal | MCU Pin | Notes |
|:--|:--|:--|
| Buzzer PWM | PB23 | TC7 WO[1], match PWM mode, prescaler 256 (187.5 kHz timer clock) |
| | | `CC0` sets the period and therefore the pitch: frequency = 187500 / (CC0 + 1) |
| | | `CC1` is set to `CC0 / 2` for a fixed 50 percent duty cycle |
| | | Drives Q8 (MMBT3904) through R22 (2.2k); D4 (1N4148W) clamps the transducer |

### LED Mapping
The STP16CPC05 receives one 16-bit word per update, transmitted MSB first over SERCOM4 SPI and then latched. Twelve of the sixteen channels are used, one per row and color combination. The table below shows which data bit and driver output each LED signal is connected to.

|_**STP16CPC05 Outputs**_|Data Bit|Signal|--|_**STP16CPC05 Outputs**_|Data Bit|Signal|
|:--:|:--:|:--:|:--:|:--:|:--:|:--:|
|Out0|Bit 0|Row 1 Red|--|Out6|Bit 6|Row 3 Red|
|Out1|Bit 1|Row 1 Green|--|Out7|Bit 7|Row 3 Green|
|Out2|Bit 2|Row 1 Blue|--|Out8|Bit 8|Row 3 Blue|
|Out3|Bit 3|Row 2 Red|--|Out9|Bit 9|Row 4 Red|
|Out4|Bit 4|Row 2 Green|--|Out10|Bit 10|Row 4 Green|
|Out5|Bit 5|Row 2 Blue|--|Out11|Bit 11|Row 4 Blue|

Out12 through Out15 are unused. In firmware each LED stores a base address for its row (`0x0001`, `0x0008`, `0x0040`, `0x0200`) and derives its green and blue masks by shifting that base left by one and two bits.

Because the row and color lines are shared, the anodes select which column is actually lit. Those column selects and the SPI control lines are:

| Signal | MCU Pin | Schematic Net | Notes |
|:--|:--|:--|:--|
| LED Column 1 | PB0 | LED Col 1 | Left column, drives Q4 into Q15 |
| LED Column 2 | PB1 | LED Col 2 | Drives Q5 into Q17 |
| LED Column 3 | PB2 | LED Col 3 | Drives Q6 into Q16 |
| LED Column 4 | PB3 | LED Col 4 | Right column, drives Q7 into Q18 |
| SPI Data Out | PB12 | SPI Dout | SERCOM4 MOSI into the driver's SIN pin |
| SPI Clock | PB13 | SPI CLK | SERCOM4 SCK |
| SPI Latch | PB14 | SPI Latch | GPIO, pulsed high then low after each 16-bit word |

Firmware addresses the LEDs by a single index from 0 to 15, laid out left to right and top to bottom:

|  |_**Column 1**_|_**Column 2**_|_**Column 3**_|_**Column 4**_|
|:--:|:--:|:--:|:--:|:--:|
|**Row 1**|LED 0|LED 1|LED 2|LED 3|
|**Row 2**|LED 4|LED 5|LED 6|LED 7|
|**Row 3**|LED 8|LED 9|LED 10|LED 11|
|**Row 4**|LED 12|LED 13|LED 14|LED 15|

### 4x4 Button Mapping
The matrix is scanned one column at a time. Each column output is driven low in turn while the four row inputs are read; a pressed switch pulls its row line low against the MCU's internal pullup. Every switch has a series 1N4148 diode on the button matrix board so that multiple simultaneous presses cannot ghost.

| Signal | MCU Pin | Schematic Net | Notes |
|:--|:--|:--|:--|
| Column 1 Drive | PB4 | Col/Output 1 | Output, left column |
| Column 2 Drive | PB5 | Col/Output 2 | Output |
| Column 3 Drive | PB6 | Col/Output 3 | Output |
| Column 4 Drive | PB7 | Col/Output 4 | Output, right column |
| Row 1 Sense | PB8 | Row/Input 1 | Input with internal pullup, top row |
| Row 2 Sense | PB9 | Row/Input 2 | Input with internal pullup |
| Row 3 Sense | PB10 | Row/Input 3 | Input with internal pullup |
| Row 4 Sense | PB11 | Row/Input 4 | Input with internal pullup |

`scanButtonMatrix()` returns a 16-bit mask where bit position is `row * 4 + column`, which matches the LED index for the same pad. The table below shows the bit each switch sets and its reference designator on the button matrix board.

|  |_**Column 1**_|_**Column 2**_|_**Column 3**_|_**Column 4**_|
|:--:|:--:|:--:|:--:|:--:|
|**Row 1**|Bit 0 (SW1)|Bit 1 (SW2)|Bit 2 (SW3)|Bit 3 (SW4)|
|**Row 2**|Bit 4 (SW5)|Bit 5 (SW6)|Bit 6 (SW7)|Bit 7 (SW8)|
|**Row 3**|Bit 8 (SW9)|Bit 9 (SW10)|Bit 10 (SW11)|Bit 11 (SW12)|
|**Row 4**|Bit 12 (SW13)|Bit 13 (SW14)|Bit 14 (SW15)|Bit 15 (SW16)|

Three additional buttons live on the main control board and are read directly rather than scanned:

| Signal | MCU Pin | Notes |
|:--|:--|:--|
| Previous Button | PB16 | Input with internal pullup, active low. Cycles backwards through the game list |
| Next Button | PB17 | Input with internal pullup, active low. Cycles forwards through the game list |
| Difficulty / Mute Button | PB22 | Input with internal pullup, active low. Tap to change difficulty, hold for one second to toggle mute |
| Reset | RESET | SW5 push button with a 10k pullup (R21) |

## 4. STL Viewer 
The enclosure was designed in Autodesk Fusion. The full Fusion archive is included alongside the exported meshes: [lumisquare.f3z](3d%20print/lumisquare.f3z)

### Full Design 
- [full-design.stl](3d%20print/full-design.stl)

### Face Plate 
- [face-plate.stl](3d%20print/face-plate.stl)

### Back Cover 
- [back-cover.stl](3d%20print/back-cover.stl)

### Main Body 
- [main-body.stl](3d%20print/main-body.stl)

### Main Control Board 
- [main-control-board.stl](3d%20print/main-control-board.stl)

---

## License
See [LICENSE](LICENSE) for details.

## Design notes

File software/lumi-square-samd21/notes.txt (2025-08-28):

ATSAMD21J18A Pinout
- pb0 - Led Column 1
- pb1 - Led Column 2
- pb2 - Led Column 3
- pb3 - Led Column 4
- pb4 - button matrix output gnd 4
- pb5 - button matrix output gnd 3
- pb6 - button matrix output gnd 2
- pb7 - button matrix output gnd 1
- pb8 - button matrix input switch 1
- pb9 - button matrix input switch 2
- pb10 - button matrix input switch 3
- pb11 - button matrix input switch 4
- pb12 - SPI Dout
- pb13 - SPI Clock
- pb14 - SPI Latch
- pb16 - Previous button
- pb17 - Next Button
- pb22 - difficulty/mute button
- pa20 - Usart Tx
- pa21 - Usart rx
- pb23 - TC7 pwm

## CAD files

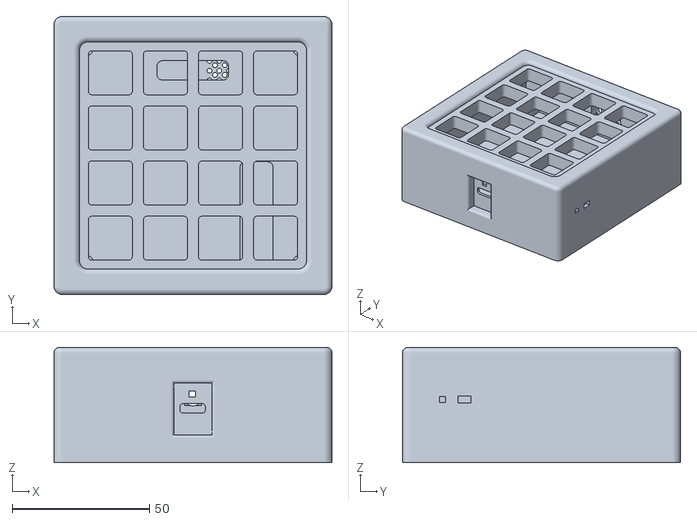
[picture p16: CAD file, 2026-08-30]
3d print/full-design.stl
101.2 x 101.2 x 42.0

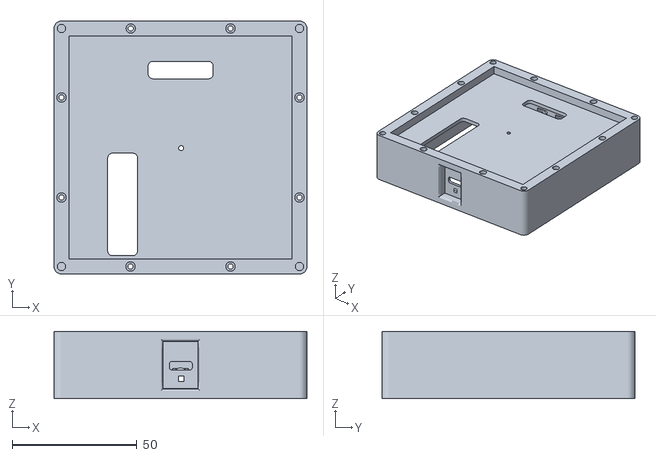
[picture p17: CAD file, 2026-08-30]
3d print/main-body.stl
101.2 x 101.2 x 27.0

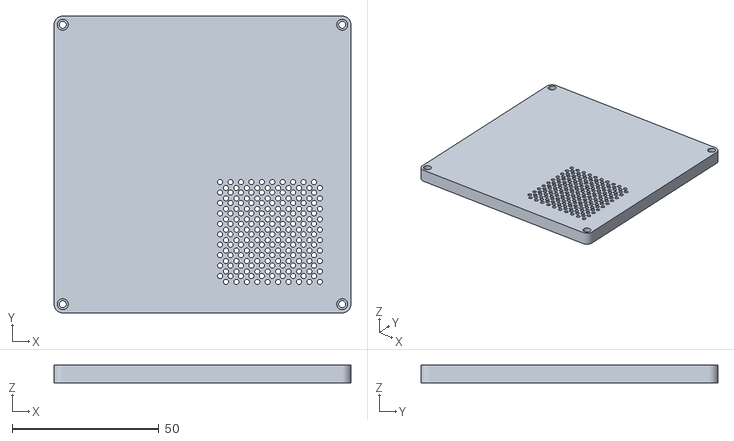
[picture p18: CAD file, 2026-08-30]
3d print/back-cover.stl
101.2 x 101.2 x 6.00

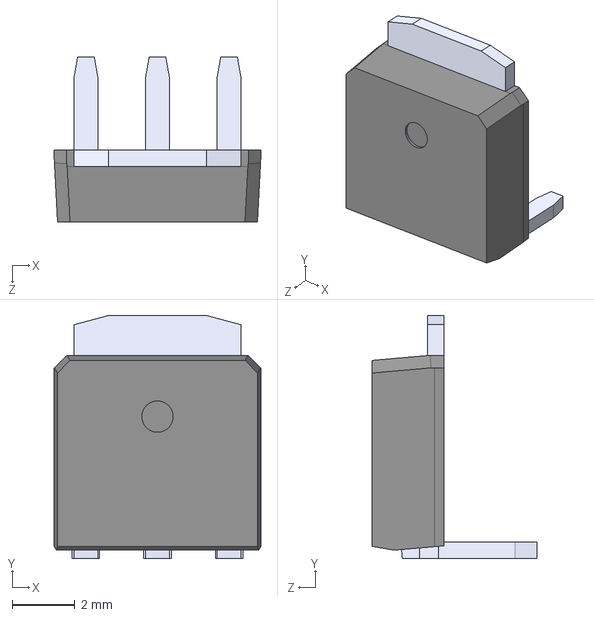
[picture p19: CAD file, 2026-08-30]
eda/step files/TSM680P06CH_pins_bent_90deg.step
6.60 x 7.77 x 5.26 mm

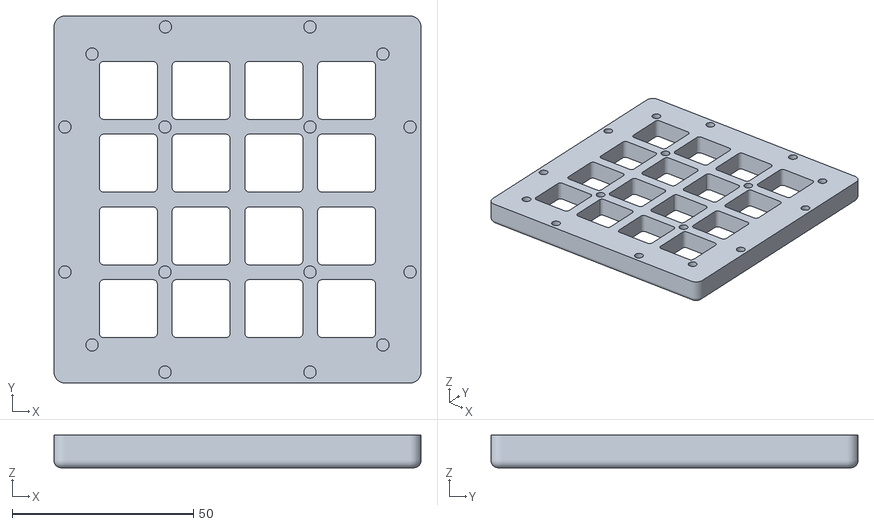
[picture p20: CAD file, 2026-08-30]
3d print/face-plate.stl
101.2 x 101.2 x 9.00

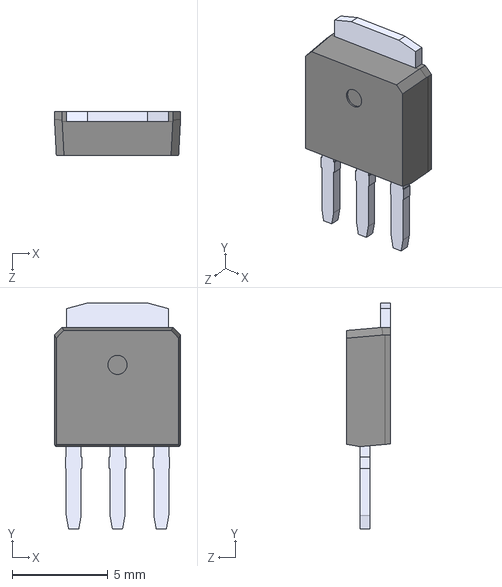
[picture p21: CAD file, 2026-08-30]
eda/step files/TSM680P06CH.step
6.60 x 11.8 x 2.30 mm

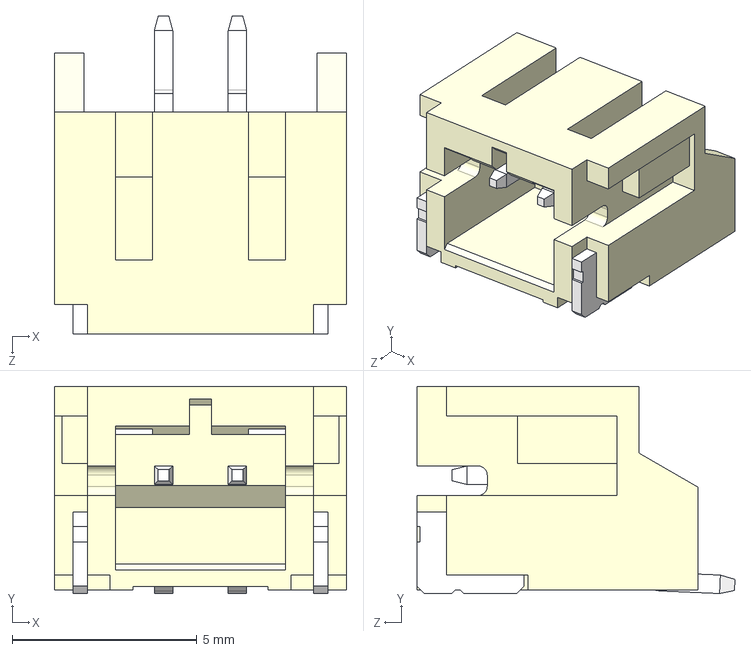
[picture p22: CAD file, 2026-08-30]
eda/step files/S2B-PH-SM4-TB--3DModel-STEP-269445.STEP
7.90 x 5.60 x 8.60 mm

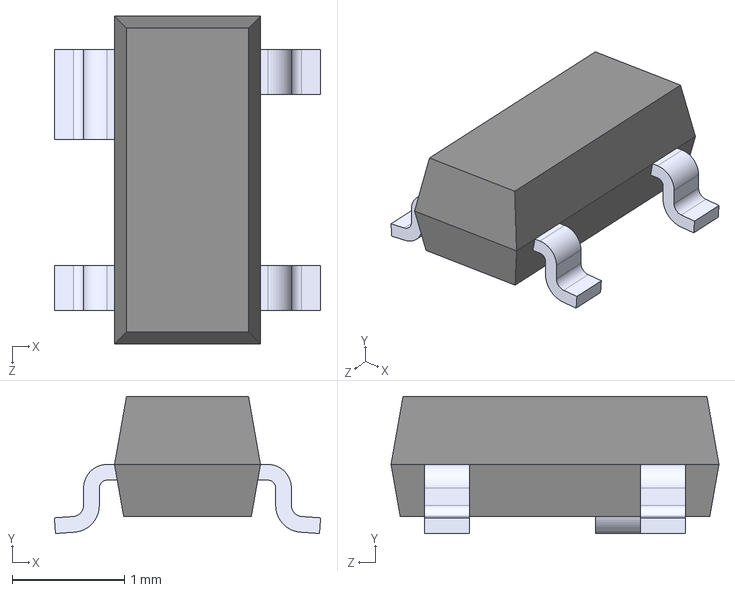
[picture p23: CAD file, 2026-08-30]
eda/step files/TPD2E001DZDR--3DModel-STEP-56544.STEP
2.37 x 1.22 x 2.92 mm

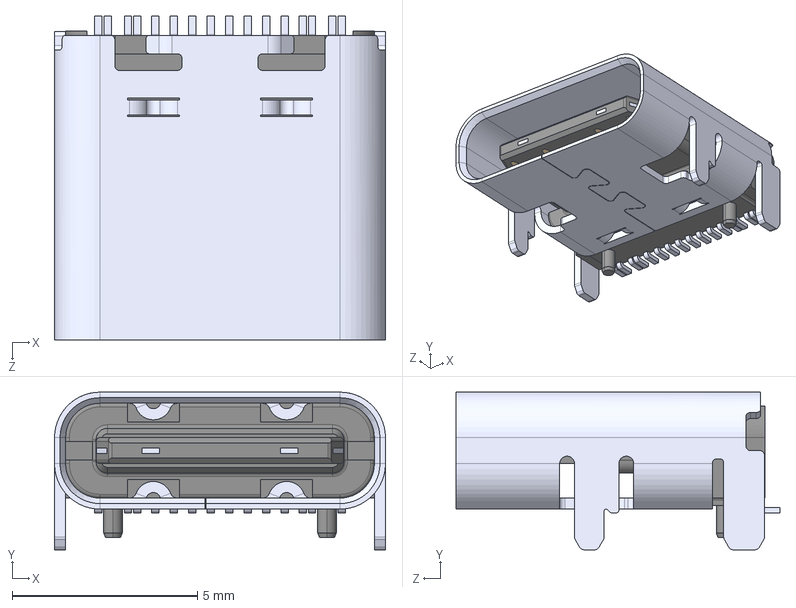
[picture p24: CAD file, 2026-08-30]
eda/step files/GT-USB-7004--3DModel-STEP-269445.STEP
8.94 x 4.26 x 8.75 mm

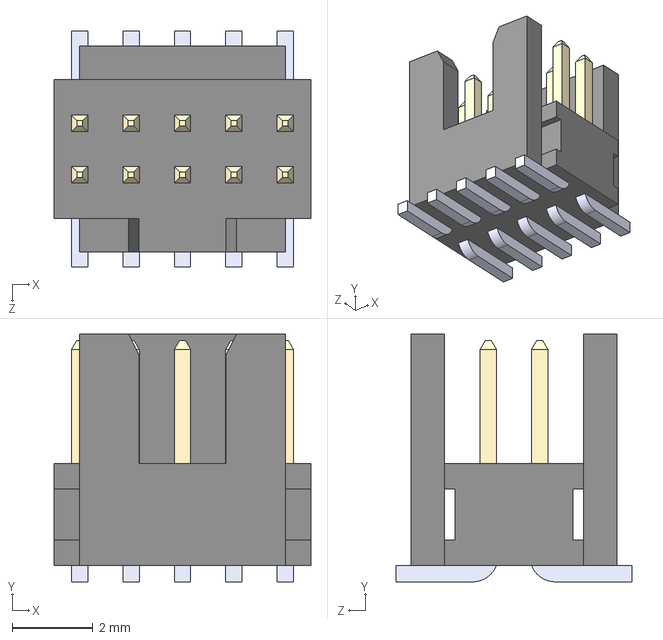
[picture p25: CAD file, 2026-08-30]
eda/step files/FTSH-105-01-X-DV-P-K-X.step
6.35 x 6.12 x 5.84 mm

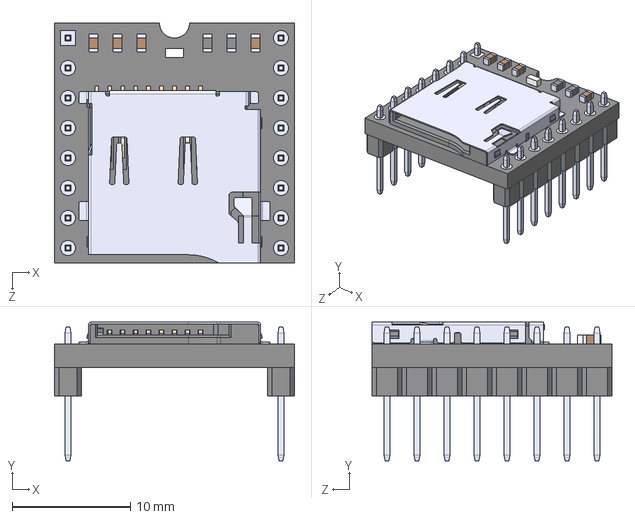
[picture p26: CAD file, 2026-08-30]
eda/step files/DFR0299.step
20.3 x 11.8 x 20.3 mm

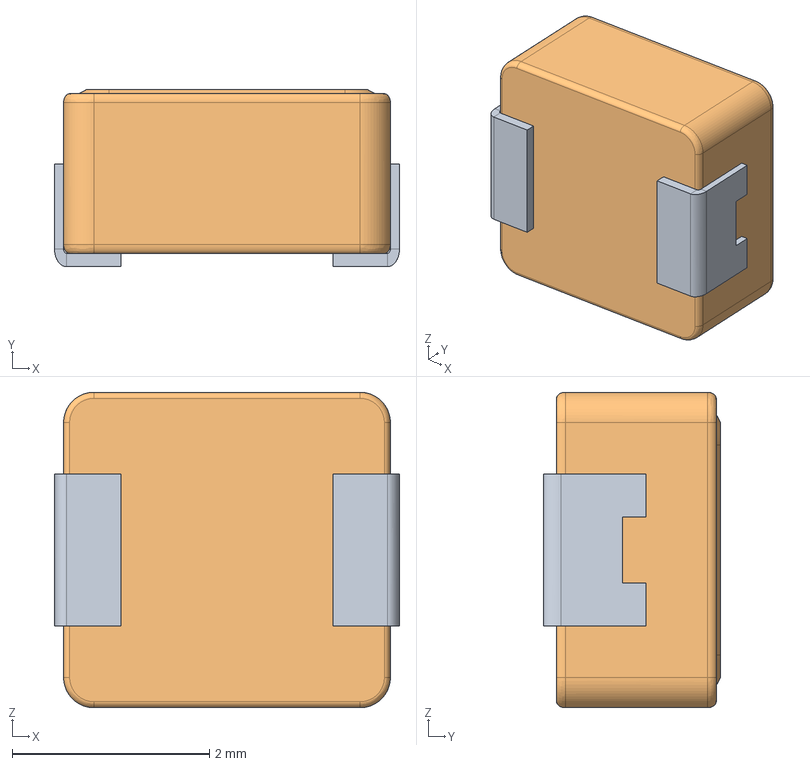
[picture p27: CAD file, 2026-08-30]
eda/step files/SRP3020TA-4R7M_scaled.step
3.50 x 1.80 x 3.20 mm

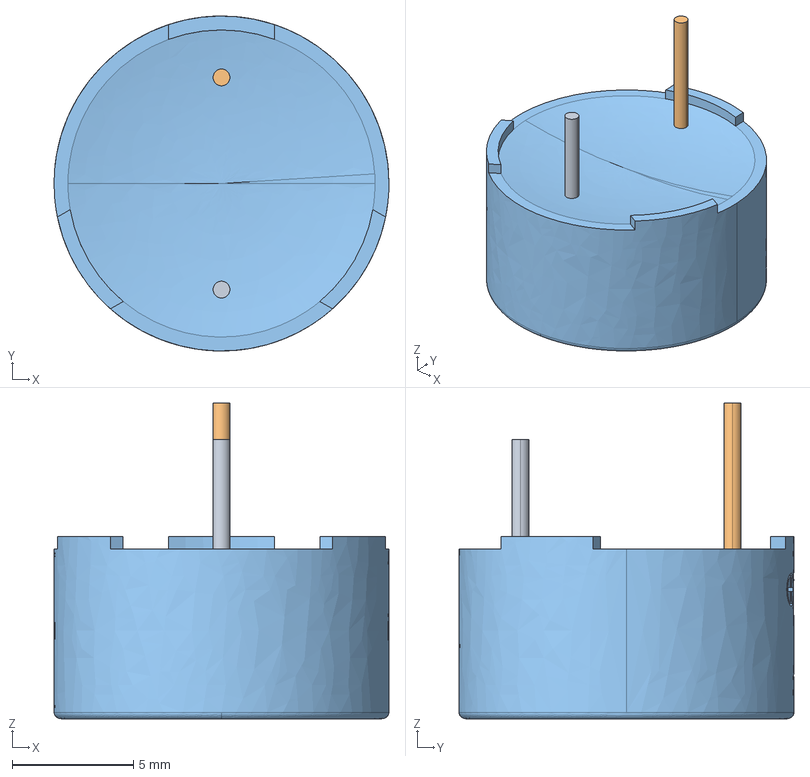
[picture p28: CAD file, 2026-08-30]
eda/step files/RDT-4.000-1375-NS1.step
13.8 x 13.8 x 13.0 mm

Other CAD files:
3d print/lumisquare.f3z

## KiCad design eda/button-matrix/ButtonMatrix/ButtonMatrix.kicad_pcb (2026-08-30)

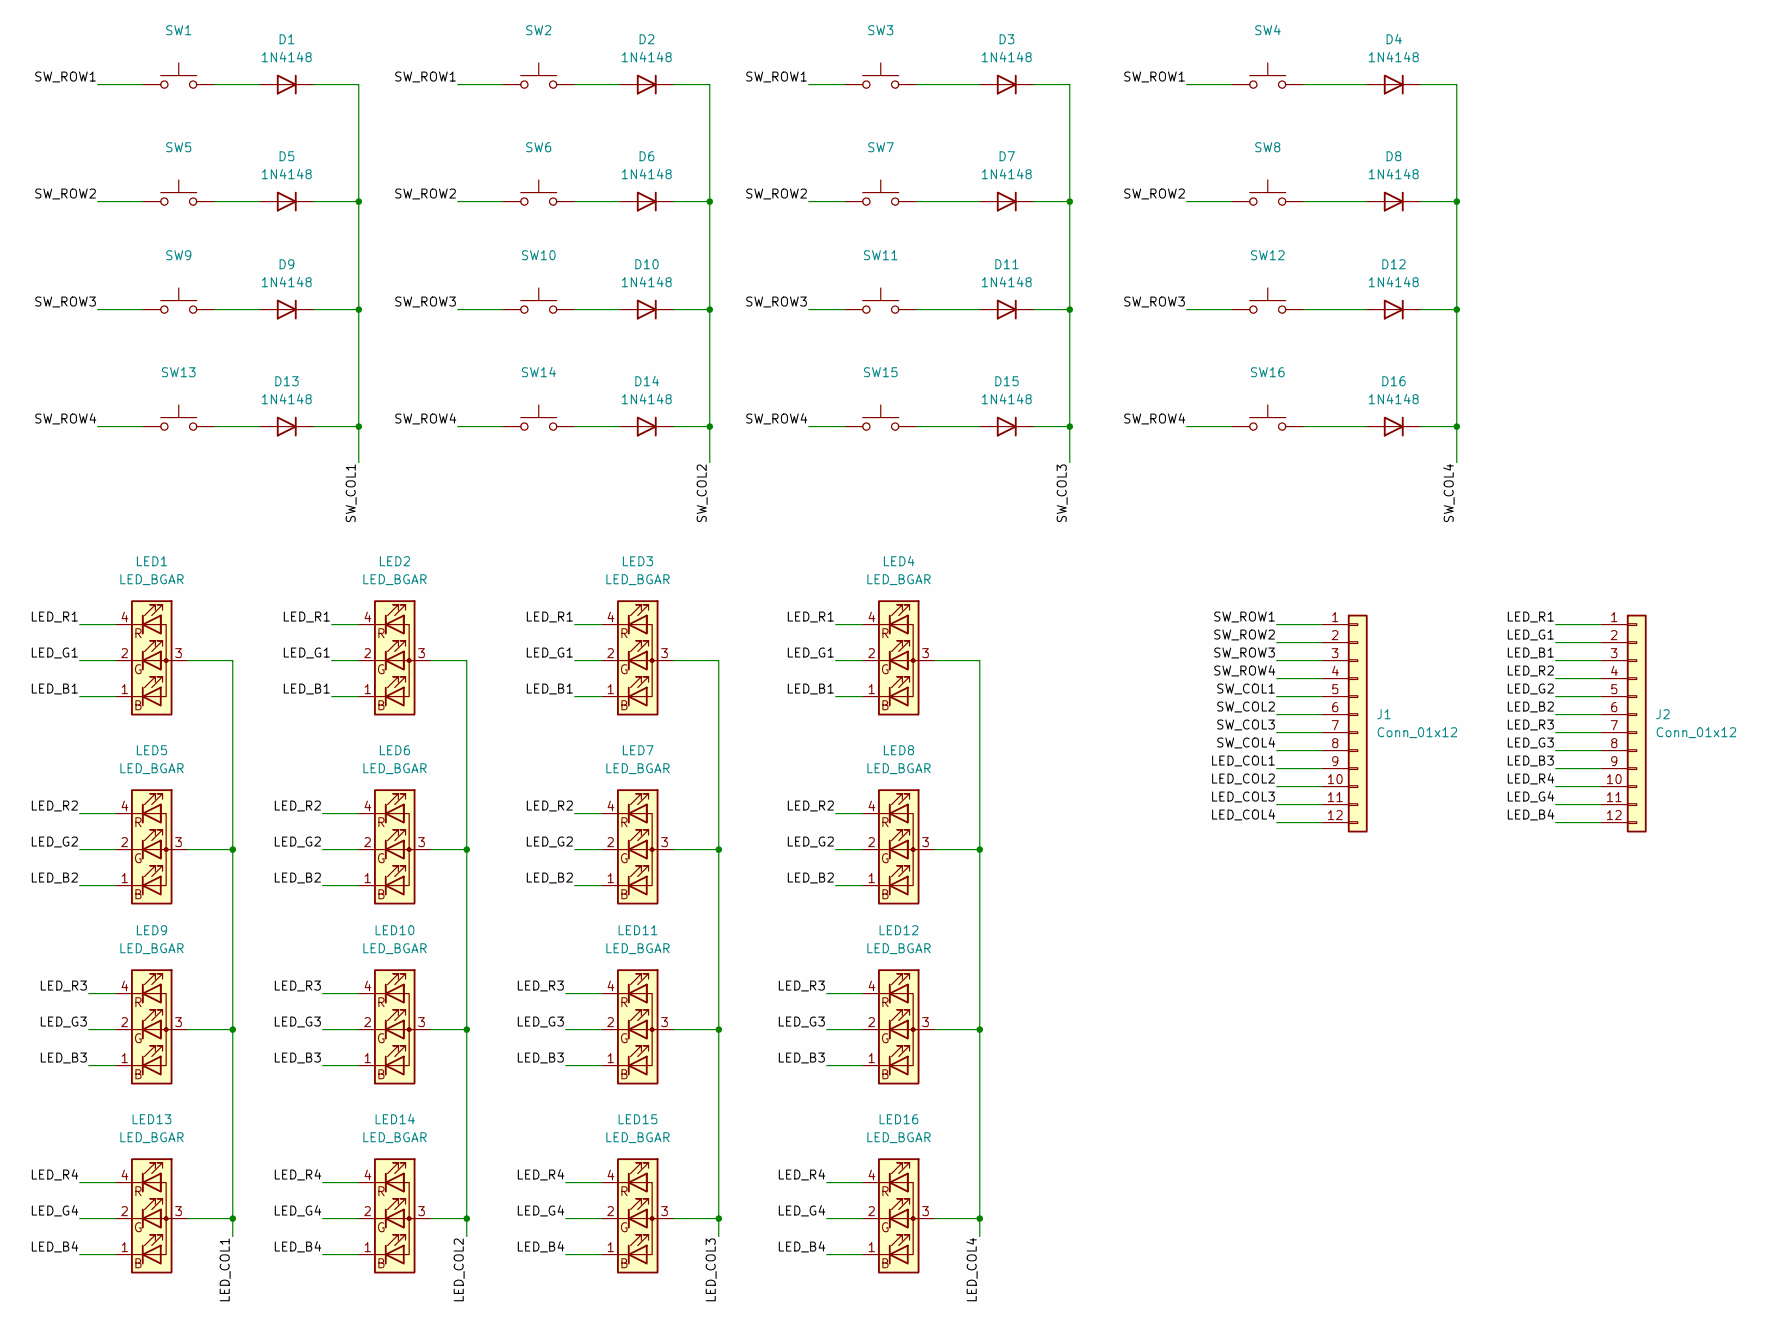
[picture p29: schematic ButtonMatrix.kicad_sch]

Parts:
D1, D2, D3, D4, D5, D6, D7, D8, D9, D10, D11, D12, D13, D14, D15, D16: 1N4148; D_DO-35_SOD27_P7.62mm_Horizontal
J1, J2: Conn_01x12; PinHeader_1x12_P2.54mm_Vertical
LED1, LED2, LED3, LED4, LED5, LED6, LED7, LED8, LED9, LED10, LED11, LED12, LED13, LED14, LED15, LED16: LED_BGAR; LED_D5.0mm-4_RGB
SW1, SW2, SW3, SW4, SW5, SW6, SW7, SW8, SW9, SW10, SW11, SW12, SW13, SW14, SW15, SW16: lumisquare button

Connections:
/LED_B1: J2.3, LED1.1 (BK), LED2.1 (BK), LED3.1 (BK), LED4.1 (BK)
/LED_B2: J2.6, LED5.1 (BK), LED6.1 (BK), LED7.1 (BK), LED8.1 (BK)
/LED_B3: J2.9, LED9.1 (BK), LED10.1 (BK), LED11.1 (BK), LED12.1 (BK)
/LED_B4: J2.12, LED13.1 (BK), LED14.1 (BK), LED15.1 (BK), LED16.1 (BK)
/LED_COL1: J1.9, LED1.3 (A), LED5.3 (A), LED9.3 (A), LED13.3 (A)
/LED_COL2: J1.10, LED2.3 (A), LED6.3 (A), LED10.3 (A), LED14.3 (A)
/LED_COL3: J1.11, LED3.3 (A), LED7.3 (A), LED11.3 (A), LED15.3 (A)
/LED_COL4: J1.12, LED4.3 (A), LED8.3 (A), LED12.3 (A), LED16.3 (A)
/LED_G1: J2.2, LED1.2 (GK), LED2.2 (GK), LED3.2 (GK), LED4.2 (GK)
/LED_G2: J2.5, LED5.2 (GK), LED6.2 (GK), LED7.2 (GK), LED8.2 (GK)
/LED_G3: J2.8, LED9.2 (GK), LED10.2 (GK), LED11.2 (GK), LED12.2 (GK)
/LED_G4: J2.11, LED13.2 (GK), LED14.2 (GK), LED15.2 (GK), LED16.2 (GK)
/LED_R1: J2.1, LED1.4 (RK), LED2.4 (RK), LED3.4 (RK), LED4.4 (RK)
/LED_R2: J2.4, LED5.4 (RK), LED6.4 (RK), LED7.4 (RK), LED8.4 (RK)
/LED_R3: J2.7, LED9.4 (RK), LED10.4 (RK), LED11.4 (RK), LED12.4 (RK)
/LED_R4: J2.10, LED13.4 (RK), LED14.4 (RK), LED15.4 (RK), LED16.4 (RK)
/SW_COL1: D1.1 (K), D5.1 (K), D9.1 (K), D13.1 (K), J1.5
/SW_COL2: D2.1 (K), D6.1 (K), D10.1 (K), D14.1 (K), J1.6
/SW_COL3: D3.1 (K), D7.1 (K), D11.1 (K), D15.1 (K), J1.7
/SW_COL4: D4.1 (K), D8.1 (K), D12.1 (K), D16.1 (K), J1.8
/SW_ROW1: J1.1, SW1.1, SW2.1, SW3.1, SW4.1
/SW_ROW2: J1.2, SW5.1, SW6.1, SW7.1, SW8.1
/SW_ROW3: J1.3, SW9.1, SW10.1, SW11.1, SW12.1
/SW_ROW4: J1.4, SW13.1, SW14.1, SW15.1, SW16.1
unnamed: D1.2 (A), SW1.2
unnamed: D2.2 (A), SW2.2
unnamed: D3.2 (A), SW3.2
unnamed: D4.2 (A), SW4.2
unnamed: D5.2 (A), SW5.2
unnamed: D6.2 (A), SW6.2
unnamed: D7.2 (A), SW7.2
unnamed: D8.2 (A), SW8.2
unnamed: D9.2 (A), SW9.2
unnamed: D10.2 (A), SW10.2
unnamed: D11.2 (A), SW11.2
unnamed: D12.2 (A), SW12.2
unnamed: D13.2 (A), SW13.2
unnamed: D14.2 (A), SW14.2
unnamed: D15.2 (A), SW15.2
unnamed: D16.2 (A), SW16.2

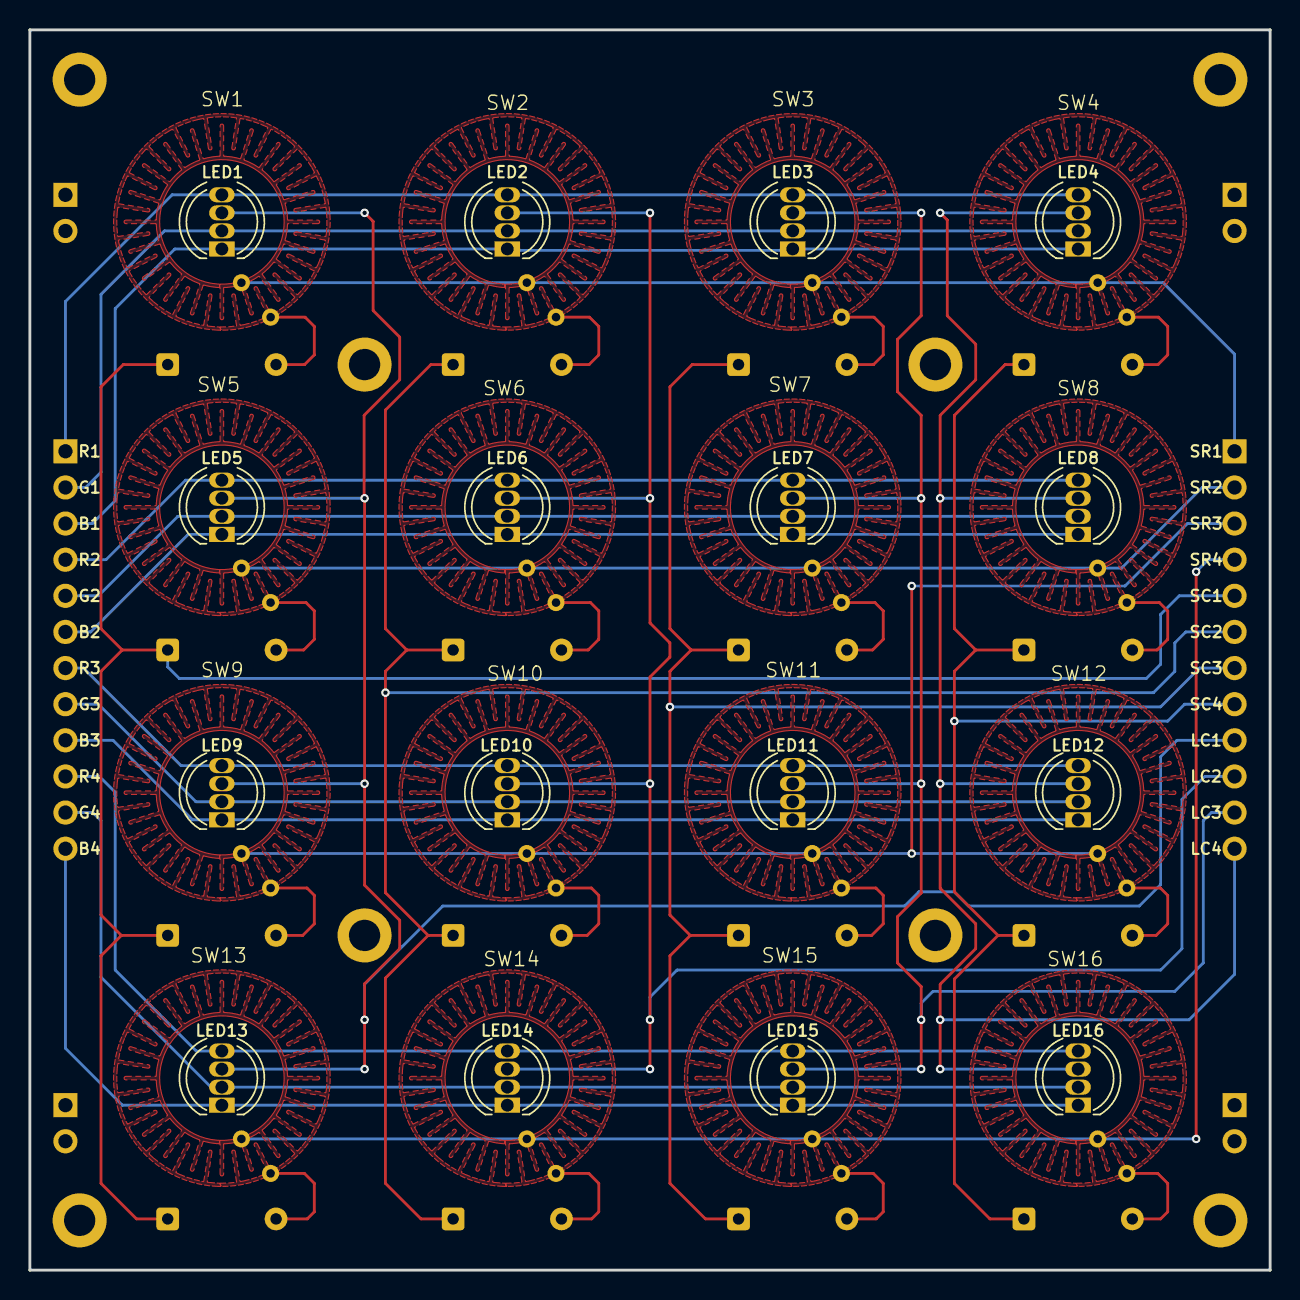
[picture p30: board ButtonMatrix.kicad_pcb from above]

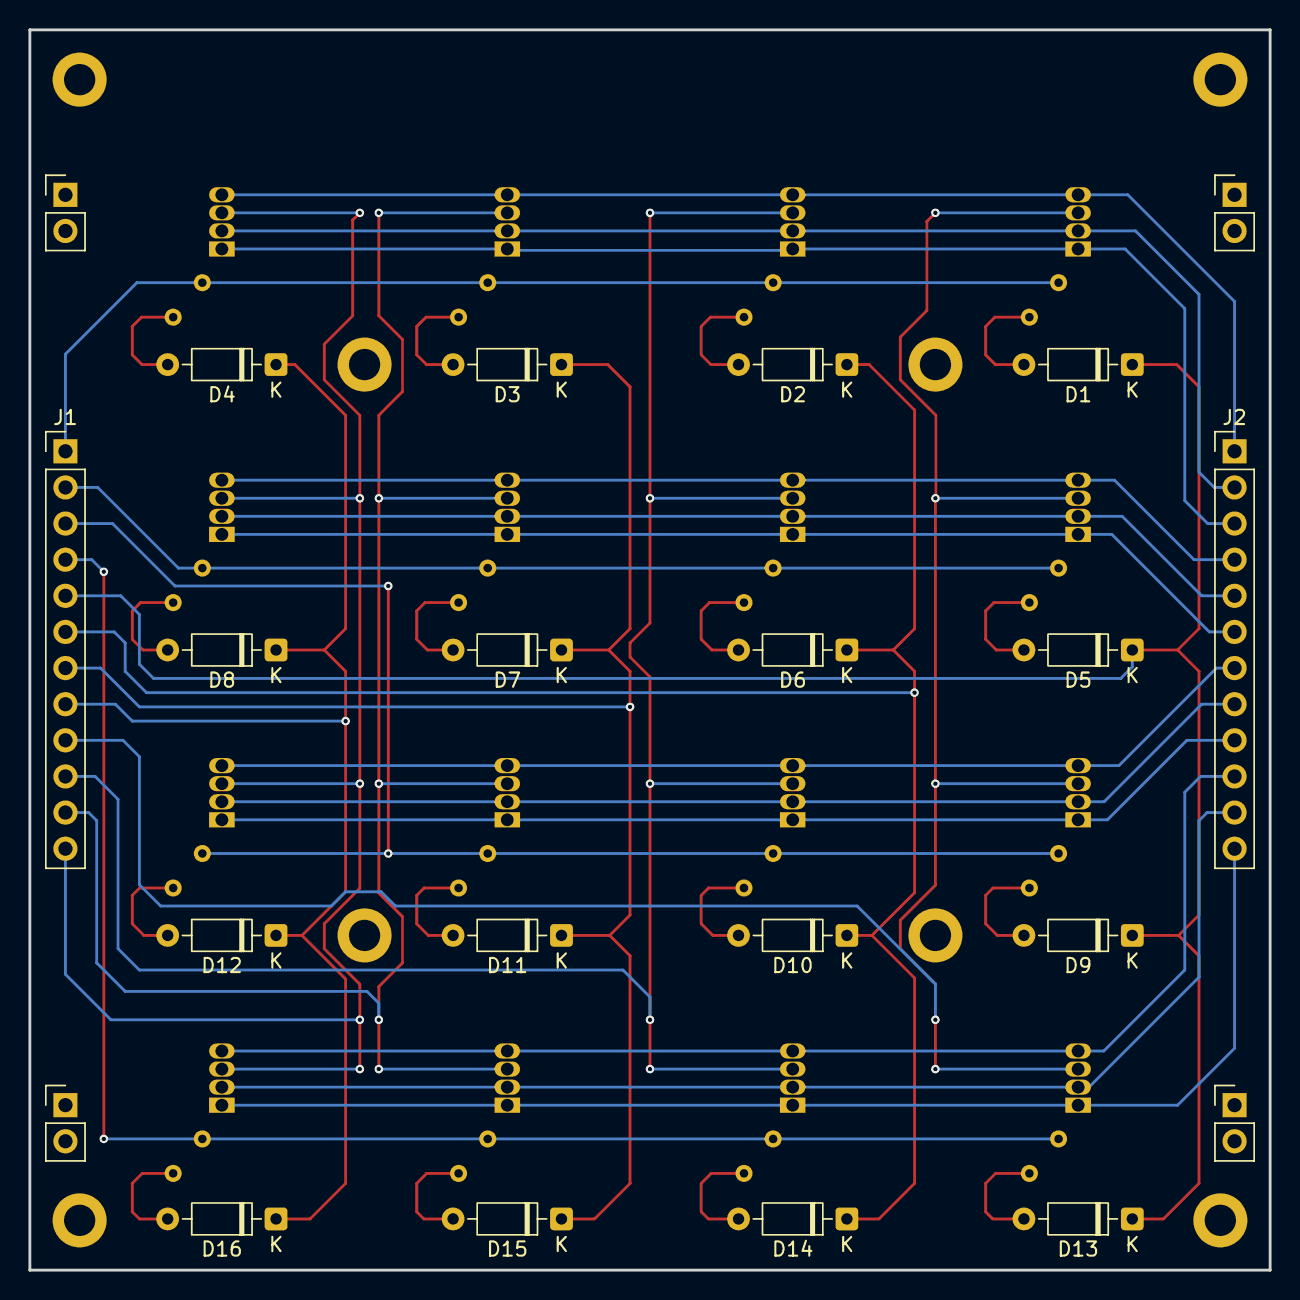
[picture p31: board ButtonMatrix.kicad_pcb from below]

Board: 2 copper layers, 87.2 x 87.2 mm, 50 parts (18 on the bottom side), 40 nets.

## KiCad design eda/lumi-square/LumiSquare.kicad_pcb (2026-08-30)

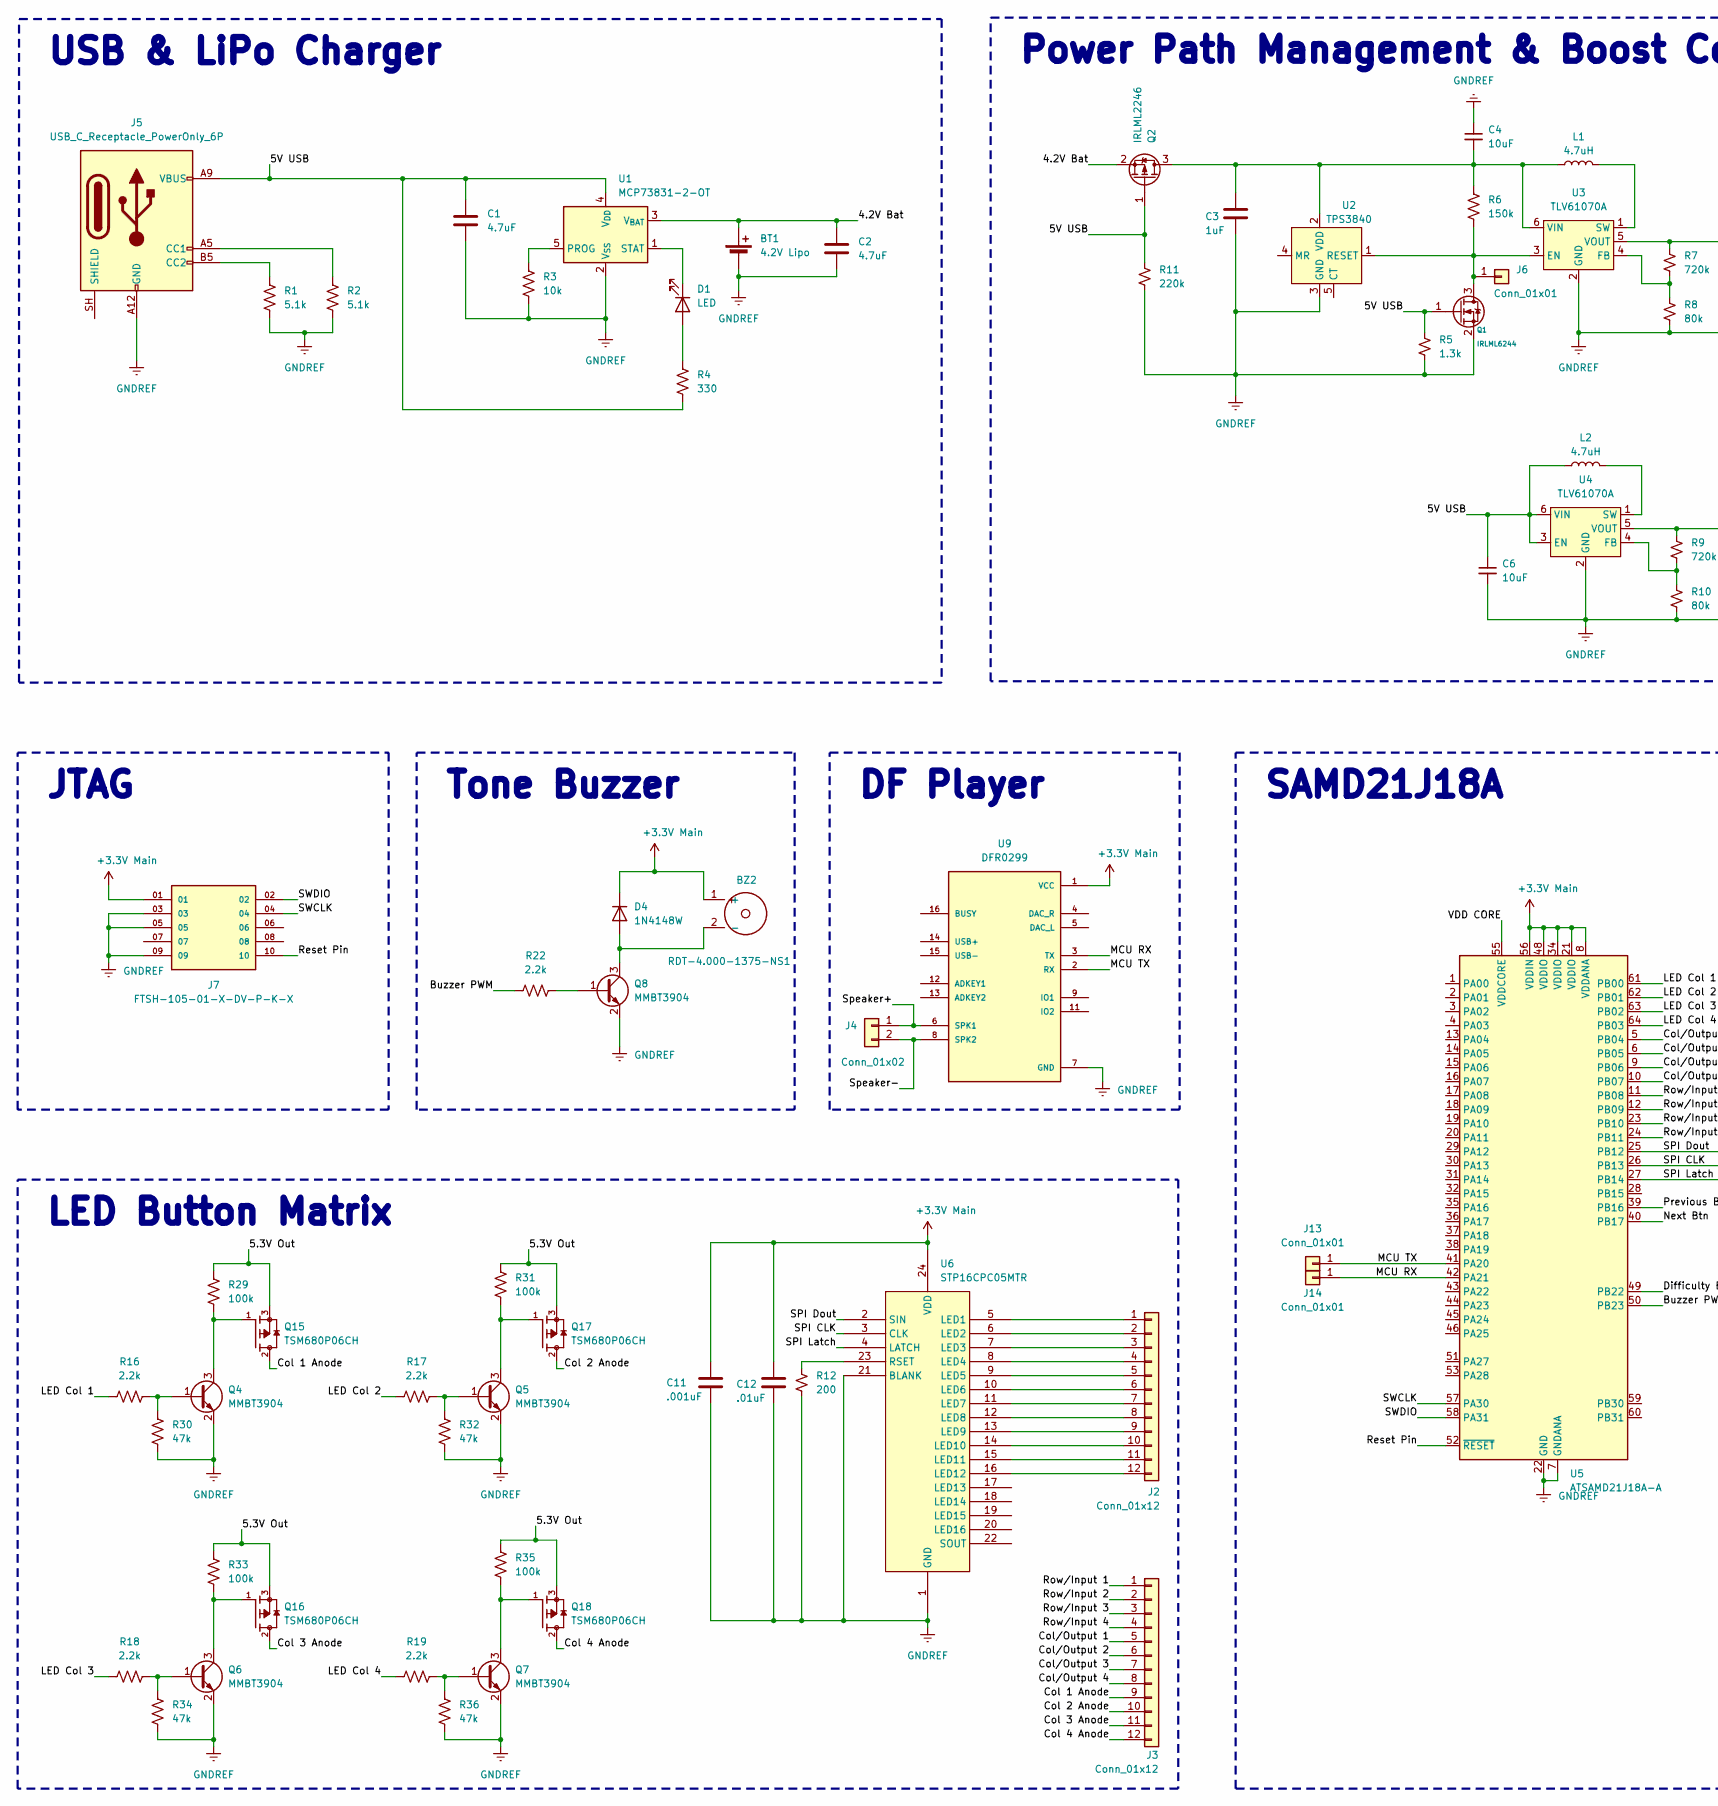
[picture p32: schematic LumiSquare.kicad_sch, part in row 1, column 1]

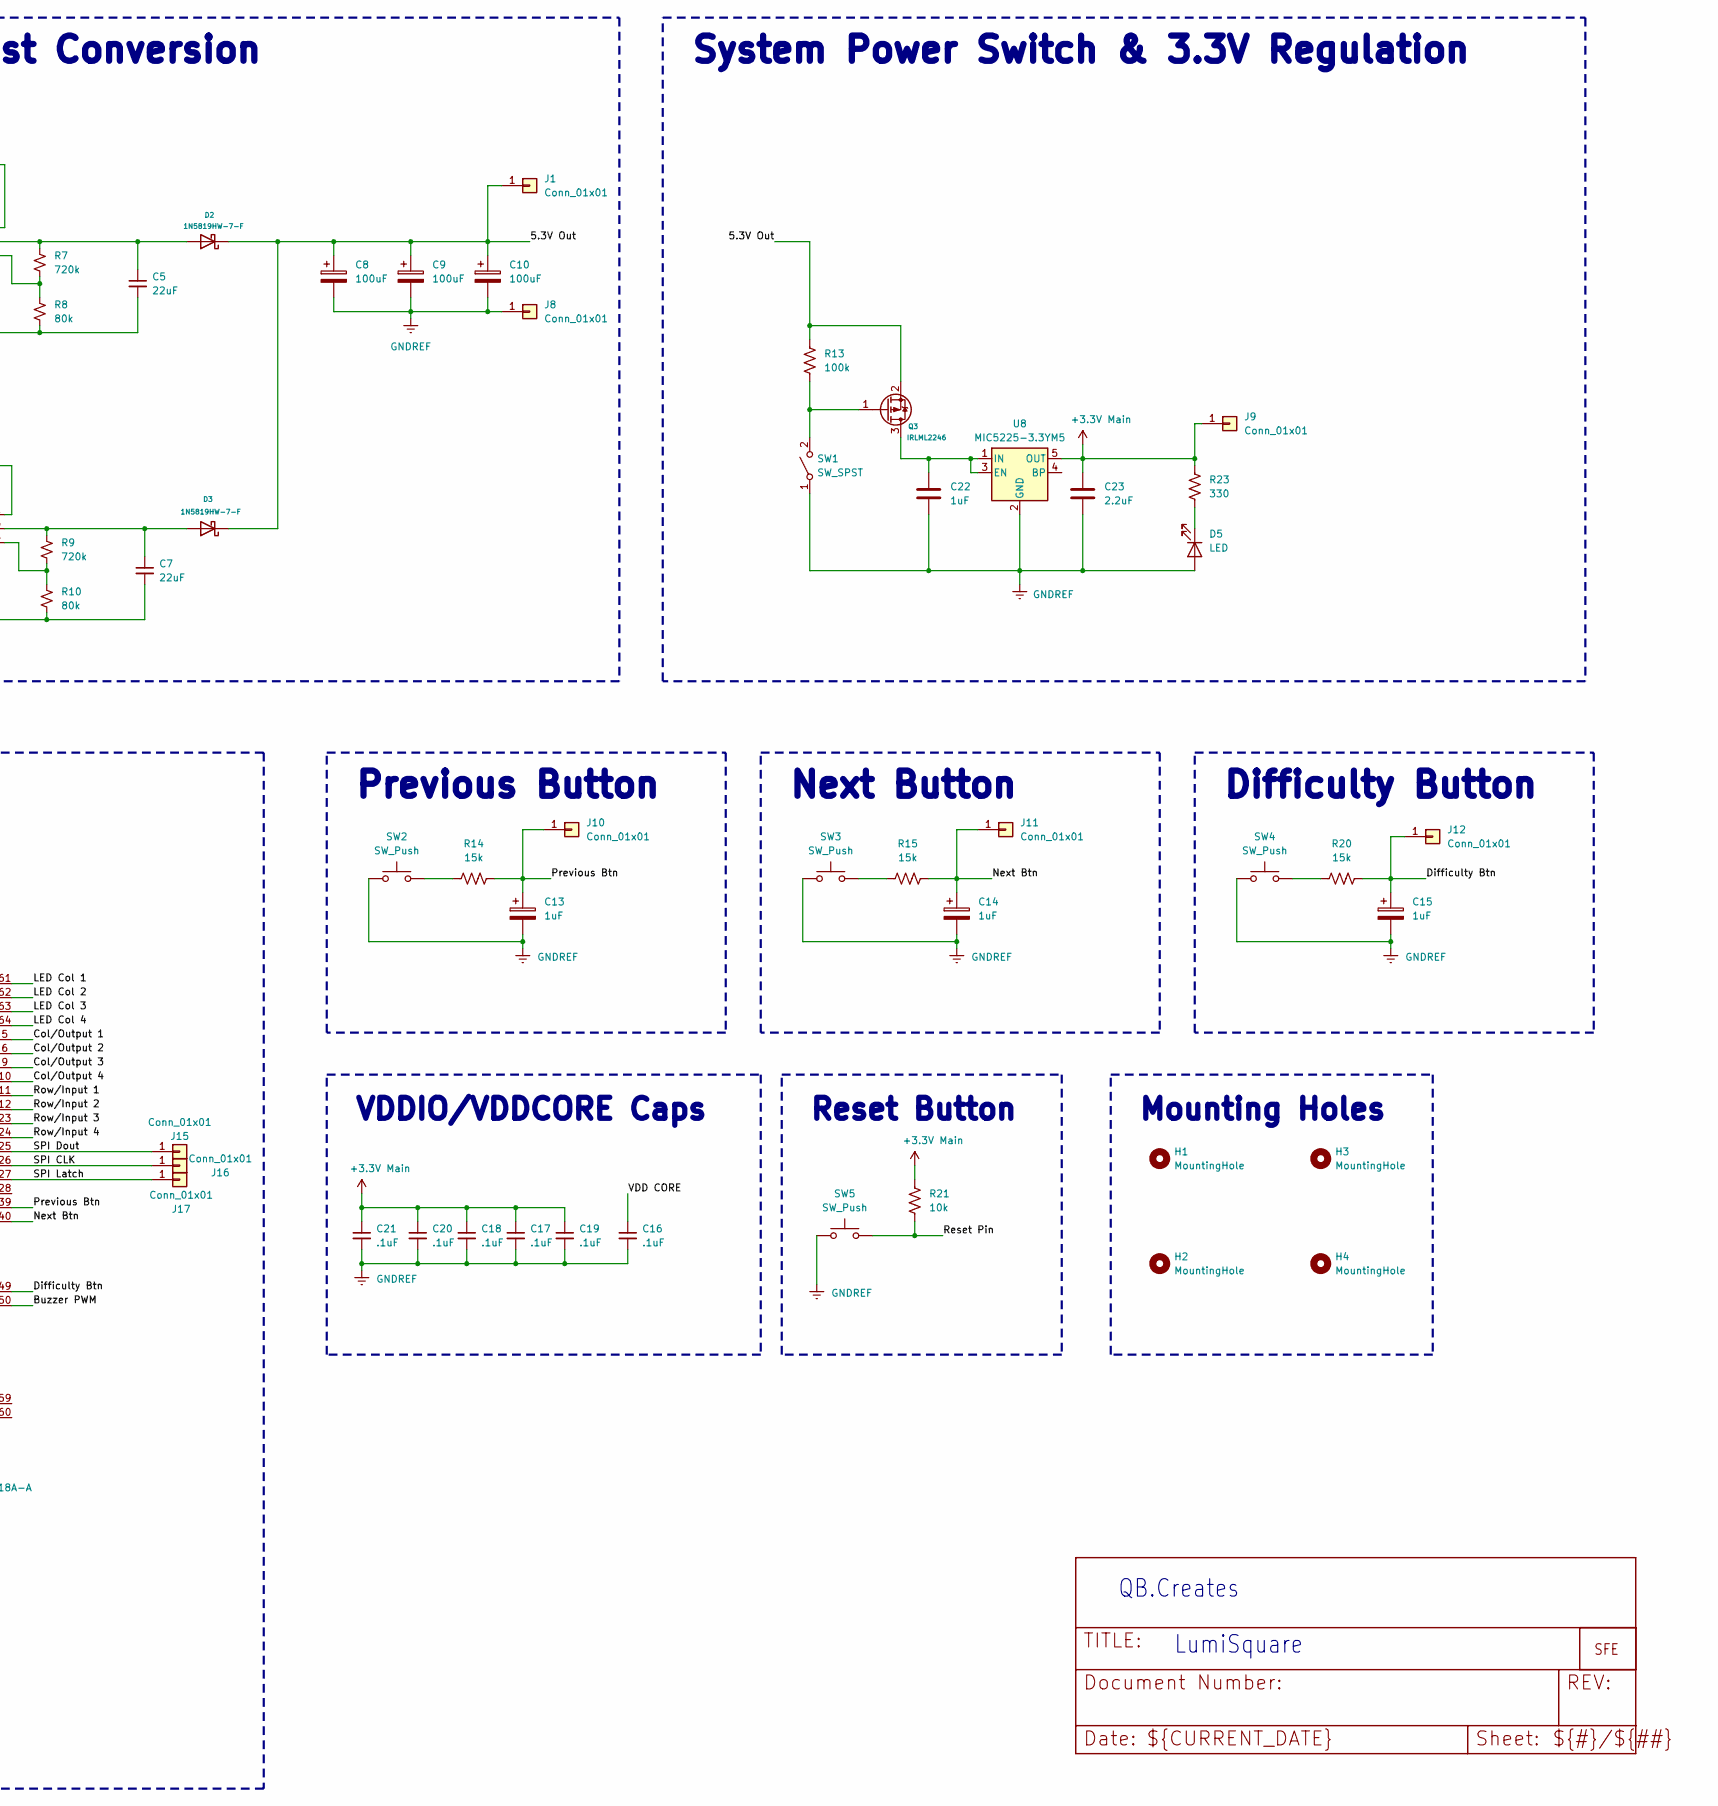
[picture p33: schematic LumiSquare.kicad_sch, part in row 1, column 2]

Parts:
BT1: 4.2V Lipo; JST_PH_S2B-PH-SM4-TB_1x02-1MP_P2.00mm_Horizontal
BZ2: RDT-4.000-1375-NS1
C1, C2: 4.7uF; C_0603_1608Metric_Pad1.08x0.95mm_HandSolder
C3, C13, C14, C15, C22: 1uF; C_0603_1608Metric_Pad1.08x0.95mm_HandSolder
C4, C6: 10uF; C_1206_3216Metric
C5, C7: 22uF; C_1206_3216Metric
C8, C9, C10: 100uF; CP_EIA-6032-28_Kemet-C_HandSolder
C11: .001uF; C_0603_1608Metric_Pad1.08x0.95mm_HandSolder
C12: .01uF; C_0603_1608Metric_Pad1.08x0.95mm_HandSolder
C16, C17, C18, C19, C20, C21: .1uF; C_0603_1608Metric_Pad1.08x0.95mm_HandSolder
C23: 2.2uF; C_0603_1608Metric_Pad1.08x0.95mm_HandSolder
D1, D5: LED; JST_SH_BM02B-SRSS-TB_1x02-1MP_P1.00mm_Vertical
D2, D3: 1N5819HW-7-F; D_SOD-123
D4: 1N4148W; D_SOD-123
H1, H2, H3, H4: MountingHole; MountingHole_2.2mm_M2_DIN965_Pad
J1, J6, J8, J9, J10, J11, J12, J13, J14, J15, J16, J17: Conn_01x01; TestPoint_Pad_D1.0mm
J2, J3: Conn_01x12; PinSocket_1x12_P2.54mm_Vertical
J4: Conn_01x02; JST_SH_SM02B-SRSS-TB_1x02-1MP_P1.00mm_Horizontal
J5: USB_C_Receptacle_PowerOnly_6P; USB_C_Receptacle_GCT_USB4125-xx-x-0190_6P_TopMnt_Horizontal
J7: FTSH-105-01-X-DV-P-K-X; SAMTEC_FTSH-105-01-X-DV-P-K-X; PARTREV H
L1, L2: 4.7uH; Bourns SRP30xx
Q1: IRLML6244; SOT-23
Q2, Q3: IRLML2246; SOT-23
Q4, Q5, Q6, Q7, Q8: MMBT3904; SOT-23
Q15, Q16, Q17, Q18: TSM680P06CH; TO228P680X245X847-3; PARTREV D14
R1, R2: 5.1k; R_0603_1608Metric_Pad0.98x0.95mm_HandSolder
R3, R21: 10k; R_0603_1608Metric_Pad0.98x0.95mm_HandSolder
R4, R23: 330; R_0603_1608Metric_Pad0.98x0.95mm_HandSolder
R5: 1.3k; R_0603_1608Metric_Pad0.98x0.95mm_HandSolder
R6: 150k; R_0603_1608Metric_Pad0.98x0.95mm_HandSolder
R7, R9: 720k; R_0603_1608Metric_Pad0.98x0.95mm_HandSolder
R8, R10: 80k; R_0603_1608Metric
R11: 220k; R_0603_1608Metric_Pad0.98x0.95mm_HandSolder
R12: 200; R_0603_1608Metric_Pad0.98x0.95mm_HandSolder
R13, R29, R31, R33, R35: 100k; R_0603_1608Metric_Pad0.98x0.95mm_HandSolder
R14, R15, R20: 15k; R_0603_1608Metric_Pad0.98x0.95mm_HandSolder
R16, R17, R18, R19, R22: 2.2k; R_0603_1608Metric_Pad0.98x0.95mm_HandSolder
R30, R32, R34, R36: 47k; R_0603_1608Metric_Pad0.98x0.95mm_HandSolder
SW1: SW_SPST; JST_SH_BM02B-SRSS-TB_1x02-1MP_P1.00mm_Vertical
SW2, SW3, SW4: SW_Push; JST_SH_BM02B-SRSS-TB_1x02-1MP_P1.00mm_Vertical
SW5: SW_Push; SW_SPST_TL3342
U1: MCP73831-2-OT; SOT-23-5
U2: TPS3840; SOT-23-5
U3, U4: TLV61070A; SOT-23-6
U5: ATSAMD21J18A-A; TQFP-64_10x10mm_P0.5mm
U6: STP16CPC05MTR; SOIC-24W_7.5x15.4mm_P1.27mm
U8: MIC5225-3.3YM5; SOT-23-5
U9: DFR0299; MODULE_DFR0299
U$1: LOGO-SFE; SFE-NEW-WEBLOGO

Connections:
+3.3V Main: BZ2.1 (+), C11.1, C12.1, C17.1, C18.1, C19.1, C20.1, C21.1, C23.1, D4.1 (K), J7.01, J9.1 (Pin_1_1), R21.1, R23.2, U5.8 (VDDANA), U5.21 (VDDIO), U5.34 (VDDIO), U5.48 (VDDIO), U5.56 (VDDIN), U6.24 (VDD), U8.5 (OUT), U9.1 (VCC)
/4.2V Bat: BT1.1 (+), C2.1, Q2.2 (S), U1.3 (V_{BAT})
/5.3V Out: C8.1, C9.1, C10.1, D2.1 (K), D3.1 (K), J1.1 (Pin_1_1), Q3.2 (S), Q15.3, Q16.3, Q17.3, Q18.3, R13.1, R29.2, R31.2, R33.2, R35.2
/5V USB: C1.1, C6.1, J5.A9 (VBUS), J5.B9 (VBUS), L2.1, Q1.1 (G), Q2.1 (G), R4.1, R5.1, R11.1, U1.4 (V_{DD}), U4.3 (EN), U4.6 (VIN)
/Buzzer PWM: R22.1, U5.50 (PB23)
/Col 1 Anode: J3.9, Q15.2
/Col 2 Anode: J3.10, Q17.2
/Col 3 Anode: J3.11, Q16.2
/Col 4 Anode: J3.12, Q18.2
/Col/Output 1: J3.5, U5.5 (PB04)
/Col/Output 2: J3.6, U5.6 (PB05)
/Col/Output 3: J3.7, U5.9 (PB06)
/Col/Output 4: J3.8, U5.10 (PB07)
/Difficulty Btn: C15.1, J12.1 (Pin_1_1), R20.2, U5.49 (PB22)
/LED Col 1: R16.1, U5.61 (PB00)
/LED Col 2: R17.1, U5.62 (PB01)
/LED Col 3: R18.1, U5.63 (PB02)
/LED Col 4: R19.1, U5.64 (PB03)
/MCU RX: J14.1 (Pin_1_1), U5.42 (PA21), U9.3 (TX)
/MCU TX: J13.1 (Pin_1_1), U5.41 (PA20), U9.2 (RX)
/Next Btn: C14.1, J11.1 (Pin_1_1), R15.2, U5.40 (PB17)
/Previous Btn: C13.1, J10.1 (Pin_1_1), R14.2, U5.39 (PB16)
/Reset Pin: J7.10, R21.2, SW5.2, U5.52 (~RESET)
/Row/Input 1: J3.1, U5.11 (PB08)
/Row/Input 2: J3.2, U5.12 (PB09)
/Row/Input 3: J3.3, U5.23 (PB10)
/Row/Input 4: J3.4, U5.24 (PB11)
/SPI CLK: J16.1 (Pin_1_1), U5.26 (PB13), U6.3 (CLK)
/SPI Dout: J15.1 (Pin_1_1), U5.25 (PB12), U6.2 (SIN)
/SPI Latch: J17.1 (Pin_1_1), U5.27 (PB14), U6.4 (LATCH)
/SWCLK: J7.04, U5.57 (PA30)
/SWDIO: J7.02, U5.58 (PA31)
/Speaker+: J4.1, U9.6 (SPK1)
/Speaker-: J4.2, U9.8 (SPK2)
/VDD CORE: C16.1, U5.55 (VDDCORE)
GNDREF: BT1.2 (-), C1.2, C2.2, C3.2, C4.1, C5.2, C6.2, C7.2, C8.2, C9.2, C10.2, C11.2, C12.2, C13.2, C14.2, C15.2, C16.2, C17.2, C18.2, C19.2, C20.2, C21.2, C22.2, C23.2, D5.2 (A), J5.A12 (GND), J5.B12 (GND), J7.03, J7.05, J7.09, J8.1 (Pin_1_1), Q1.2 (S), Q4.2 (E), Q5.2 (E), Q6.2 (E), Q7.2 (E), Q8.2 (E), R1.2, R2.2, R3.2, R5.2, R8.2, R10.2, R11.2, R12.2, R30.1, R32.1, R34.1, R36.1, SW1.1 (A), SW2.1, SW3.1, SW4.1, SW5.1, U1.2 (V_{SS}), U2.3 (GND), U3.2 (GND), U4.2 (GND), U5.7 (GNDANA), U5.22 (GND), U5.33 (GND), U5.47 (GND), U5.54 (GND), U6.1 (GND), U6.21 (BLANK), U8.2 (GND), U9.7 (GND), U9.10 (GND)
unnamed: BZ2.2 (-), D4.2 (A), Q8.3 (C)
unnamed: D1.2 (A), R4.2
unnamed: D1.1 (K), U1.1 (STAT)
unnamed: C5.1, D2.2 (A), R7.1, U3.5 (VOUT)
unnamed: C7.1, D3.2 (A), R9.1, U4.5 (VOUT)
unnamed: D5.1 (K), R23.1
unnamed: J2.1, U6.5 (LED1)
unnamed: J2.2, U6.6 (LED2)
unnamed: J2.3, U6.7 (LED3)
unnamed: J2.4, U6.8 (LED4)
unnamed: J2.5, U6.9 (LED5)
unnamed: J2.6, U6.10 (LED6)
unnamed: J2.7, U6.11 (LED7)
unnamed: J2.8, U6.12 (LED8)
unnamed: J2.9, U6.13 (LED9)
unnamed: J2.10, U6.14 (LED10)
unnamed: J2.11, U6.15 (LED11)
unnamed: J2.12, U6.16 (LED12)
unnamed: J5.A5 (CC1), R2.1
unnamed: J5.B5 (CC2), R1.1
unnamed: J6.1 (Pin_1_1), Q1.3 (D), R6.2, U2.1 (RESET), U3.3 (EN)
unnamed: C3.1, C4.2, L1.1, Q2.3 (D), R6.1, U2.2 (VDD), U3.6 (VIN)
unnamed: C22.1, Q3.3 (D), U8.1 (IN), U8.3 (EN)
unnamed: Q3.1 (G), R13.2, SW1.2 (B)
unnamed: Q4.1 (B), R16.2, R30.2
unnamed: Q4.3 (C), Q15.1, R29.1
unnamed: Q5.1 (B), R17.2, R32.2
unnamed: Q5.3 (C), Q17.1, R31.1
unnamed: Q6.1 (B), R18.2, R34.2
unnamed: Q6.3 (C), Q16.1, R33.1
unnamed: Q7.1 (B), R19.2, R36.2
unnamed: Q7.3 (C), Q18.1, R35.1
unnamed: Q8.1 (B), R22.2
unnamed: R14.1, SW2.2
unnamed: R15.1, SW3.2
unnamed: R20.1, SW4.2
unnamed: R3.1, U1.5 (PROG)
unnamed: R7.2, R8.1, U3.4 (FB)
unnamed: L1.2, U3.1 (SW)
unnamed: R9.2, R10.1, U4.4 (FB)
unnamed: L2.2, U4.1 (SW)
unnamed: R12.1, U6.23 (RSET)

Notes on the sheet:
USB & LiPo Charger
SAMD21J18A
Mounting Holes
VDDIO/VDDCORE Caps
Reset Button
DF Player
Power Path Management & Boost Conversion
Tone Buzzer
Next Button
System Power Switch & 3.3V Regulation
LumiSquare
Previous Button
JTAG
QB.Creates
LED Button Matrix
Difficulty Button

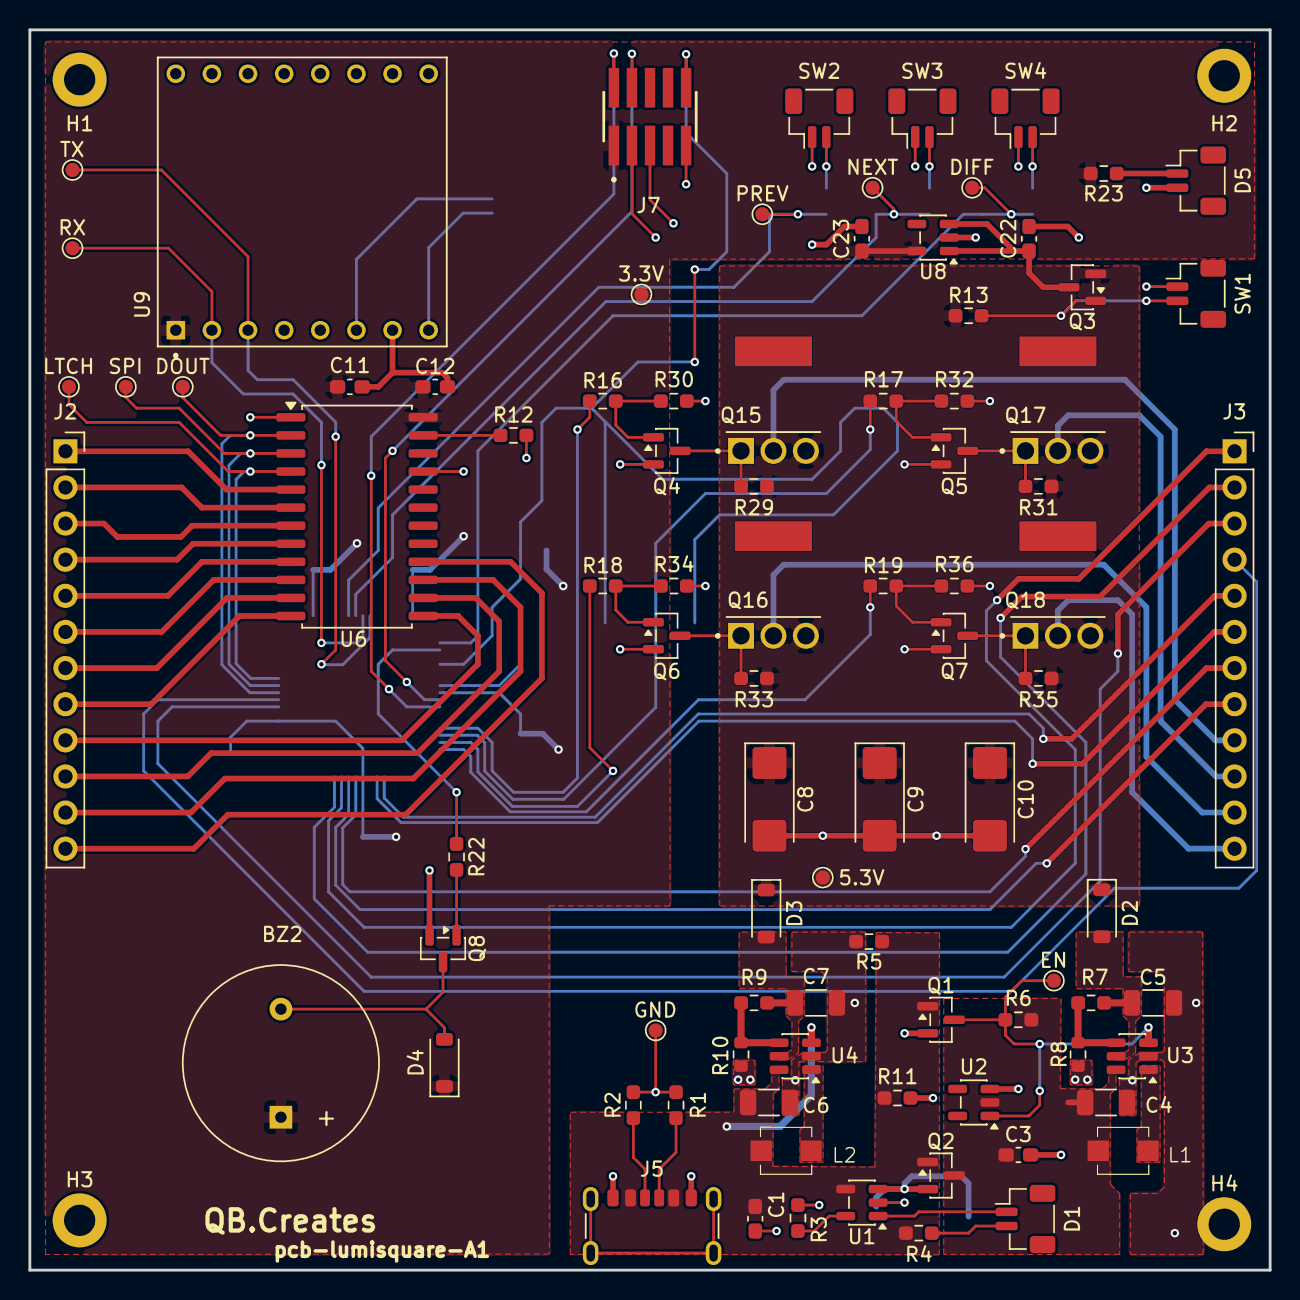
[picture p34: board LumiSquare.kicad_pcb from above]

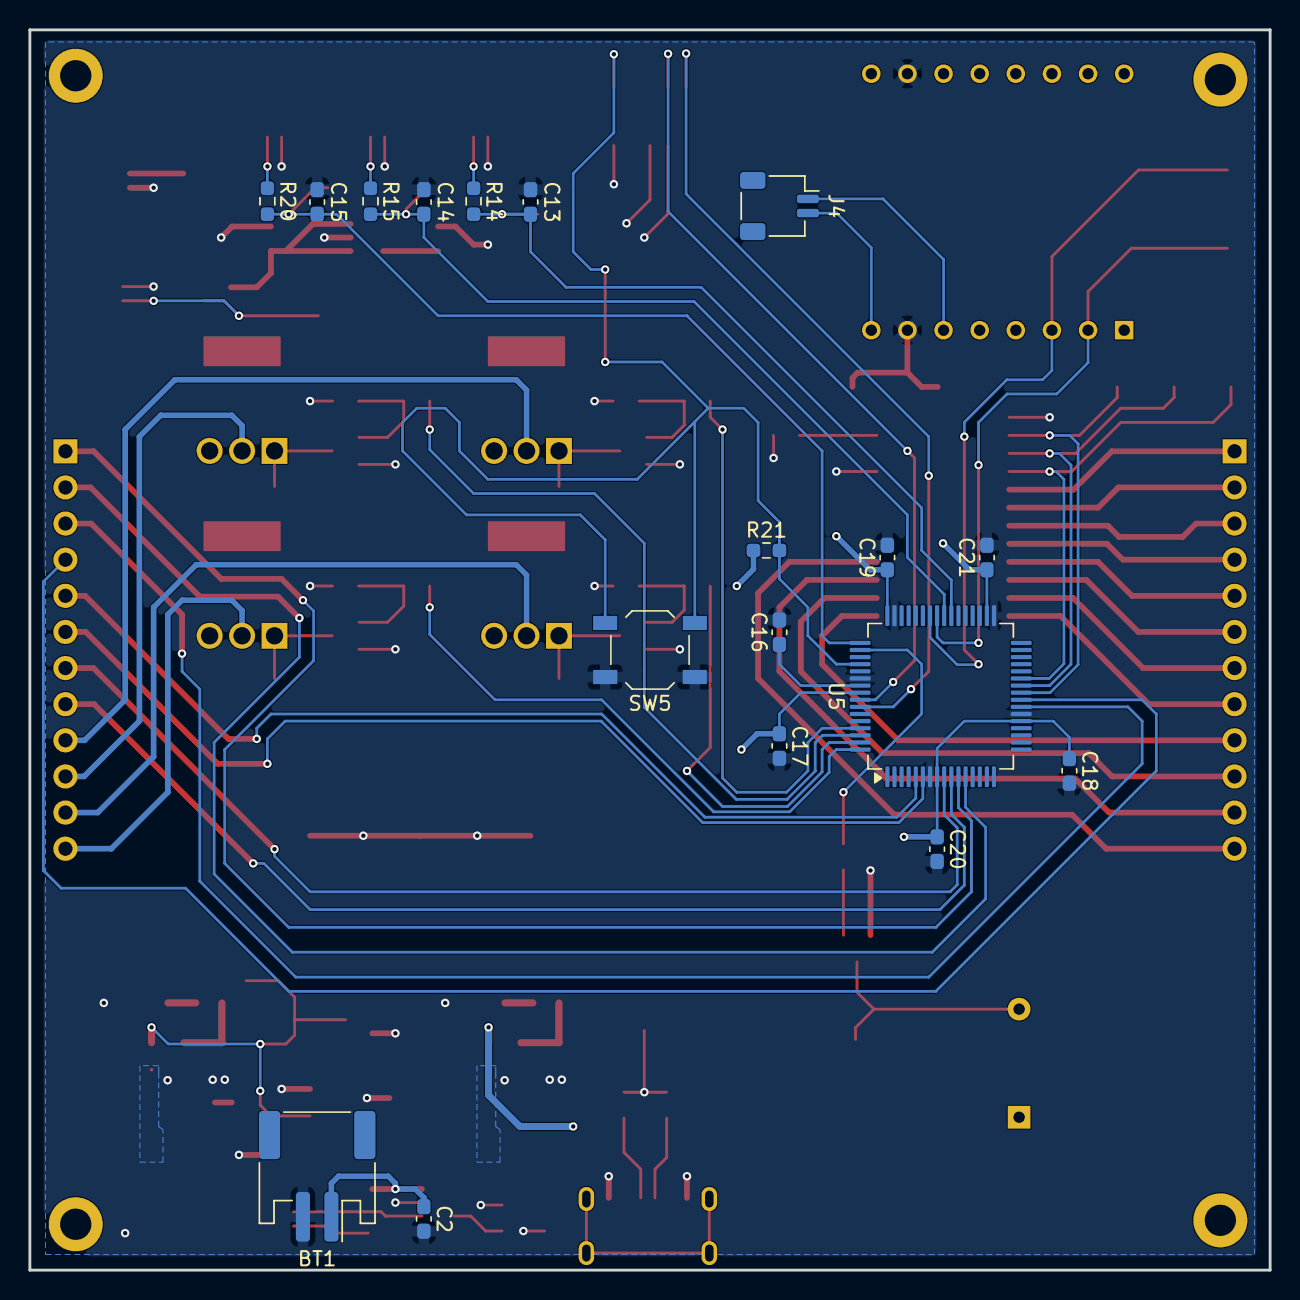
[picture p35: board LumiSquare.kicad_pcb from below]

Board: 2 copper layers, 87.2 x 87.2 mm, 109 parts (18 on the bottom side), 78 nets.

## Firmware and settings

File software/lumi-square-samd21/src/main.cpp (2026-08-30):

#include "audio.h"
#include "buttons.h"
#include "deviceutility.h"
#include "ledmatrix.h"
#include "random.h"
#include "serialcommandmanager.h"
#include "shutdownutility.h"
#include "statemanager.h"

#ifndef DESKTOP_SIMULATION
#include <samd21j18a.h>
#include <system_samd21.h>
#endif

#ifndef DESKTOP_SIMULATION
volatile uint32_t msTicks = 0;
extern "C" void SysTick_Handler(void)
{
    msTicks++;
}

void delayMS(uint32_t ms)
{
    uint64_t targetTicks = msTicks + ms;
    while (msTicks < targetTicks)
        ;
}
#endif

int main(void)
{
#ifndef DESKTOP_SIMULATION
    SystemInit();
    delayMS(1000);
#endif

    // Configure
    DeviceUtility::Instance().configure();

    while (true)
    {
        LEDMatrix::refreshLeds();

        if (!DeviceUtility::fixedUpdate)
            continue;

        DeviceUtility::fixedUpdate = false;
        Input::pollButtons();

        StateManager::Instance().onFixedUpdate();
        AudioSource::Instance().onFixedUpdate();
        ShutdownUtility::Instance().onFixedUpdate();
        SerialCommandManager::Instance().onFixedUpdate();
    }

    return 1;
}

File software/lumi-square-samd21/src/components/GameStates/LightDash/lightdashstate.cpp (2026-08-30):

#include "lightdashstate.h"
#include "ledmatrix.h"
#include "random.h"

LightDashState::LightDashState()
    : GameBaseState(GameState::LightDash),
      timer(30000),
      scoreDeductionAmount(0),
      bonusLedPointValue(0),
      maxLedTurnOffTime(1500),
      minLedTurnOffTime(500),
      bonusLedTurnOffTime(500),
      bonusLedActive(false),
      ledTurnOffTimers{(30), (30), (30), (30), (30), (30), (30), (30), (30), (30), (30), (30), (30), (30), (30), (30)} {}

void LightDashState::enterState(GameState previousState)
{
    GameBaseState::enterState(previousState);
    Difficulty difficulty = GameProperties::Instance().gameDifficulty;

    switch (difficulty)
    {
    case Difficulty::Easy:
        maxLedTurnOffTime = 2500;
        minLedTurnOffTime = 1500;
        break;
    case Difficulty::Medium:
        maxLedTurnOffTime = 2000;
        minLedTurnOffTime = 1000;
        break;
    case Difficulty::Hard:
        maxLedTurnOffTime = 1200;
        minLedTurnOffTime = 750;
        break;
    }

    scoreDeductionAmount = -(static_cast<uint8_t>(difficulty) + 1);
    bonusLedPointValue = difficulty != Difficulty::Medium ? 5 : 3;
    bonusLedTurnOffTime = difficulty != Difficulty::Medium ? 400 : 500;
    enablePowerUps = difficulty != Difficulty::Easy;

    uint8_t i = 0;

    while (i < 5)
    {
        int ledIndex = Random::range(0, 15);

        if (LEDMatrix::getLedStatus(ledIndex))
            continue;

        LEDMatrix::setLedColor(ledIndex, Colors::turquoise, .8);
        LEDMatrix::ledOn(ledIndex);
        ledTurnOffTimers[ledIndex].setTargetTime(Random::range(minLedTurnOffTime, maxLedTurnOffTime));
        ++i;
    }

    ScoreManager::Instance().resetScore(currentState, GameProperties::Instance().gameDifficulty);
}

void LightDashState::exitState()
{
    timer.resetTimer();
    nextState = GameState::None;
}

void LightDashState::updateState()
{
    updateLedOffTimers();

    timer.updateTimer(DeviceUtility::DELTA_TIME);

    if (timer.isComplete())
    {
        ScoreManager::Instance().setHighScore();
        nextState = GameState::GameOver;
    }
}

void LightDashState::onButtonPressed(int8_t buttonIndex)
{
    if (!LEDMatrix::getLedStatus(buttonIndex))
    {
        deductPointsFromScore();
        AudioSource::Instance().playMusicNote(MusicNote::B3, 50);
        return;
    }

    turnOnRandomLed();
    turnOffSelectedLed(buttonIndex);
    playMusicNote(buttonIndex);
    addPointsToScore(buttonIndex);
}

void LightDashState::updateLedOffTimers()
{
    for (int ledIndex = 0; ledIndex < 16; ++ledIndex)
    {
        if (!LEDMatrix::getLedStatus(ledIndex))
        {
            continue;
        }

        ledTurnOffTimers[ledIndex].updateTimer(DeviceUtility::DELTA_TIME);

        if (ledTurnOffTimers[ledIndex].isComplete())
        {
            turnOnRandomLed();

            if (LEDMatrix::getLedColor(ledIndex) == Colors::green)
            {
                bonusLedActive = false;
            }

            LEDMatrix::ledOff(ledIndex);
        }
    }
}

void LightDashState::turnOnRandomLed()
{
    while (1)
    {
        int ledIndex = Random::range(0, 15);
        Color ledColor = Colors::turquoise;

        if (LEDMatrix::getLedStatus(ledIndex))
            continue;

        if (GameProperties::Instance().gameDifficulty != Difficulty::Easy)
        {
            int randomNumber = Random::range(1, 20);

            if (!bonusLedActive && randomNumber == 5)
            {
                ledColor = Colors::green;
                bonusLedActive = true;
            }
        }

        int16_t turnOffTime = ledColor != Colors::turquoise ? bonusLedTurnOffTime : Random::range(minLedTurnOffTime, maxLedTurnOffTime);
        ledTurnOffTimers[ledIndex].setTargetTime(turnOffTime);

        LEDMatrix::setLedColor(ledIndex, ledColor, .8);
        LEDMatrix::ledOn(ledIndex);
        break;
    }
}

void LightDashState::turnOffSelectedLed(int8_t buttonIndex)
{
    Color buttonColor = LEDMatrix::getLedColor(buttonIndex);

    if (buttonColor == Colors::green)
    {
        bonusLedActive = false;
    }

    LEDMatrix::ledOff(buttonIndex);
}

void LightDashState::deductPointsFromScore()
{
    ScoreManager::Instance().addToScore(scoreDeductionAmount);
}

void LightDashState::addPointsToScore(int8_t buttonIndex)
{
    Color buttonColor = LEDMatrix::getLedColor(buttonIndex);
    int points = buttonColor == Colors::turquoise ? 1 : bonusLedPointValue;
    ScoreManager::Instance().addToScore(points);
}

void LightDashState::playMusicNote(int8_t buttonIndex)
{
    Color buttonColor = LEDMatrix::getLedColor(buttonIndex);
    MusicNote musicNote = buttonColor == Colors::turquoise ? MusicNote::G4 : MusicNote::A4;
    AudioSource::Instance().playMusicNote(musicNote, 50);
}

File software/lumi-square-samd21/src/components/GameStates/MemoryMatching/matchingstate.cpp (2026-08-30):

#include "./matchingstate.h"
#include "../../Peripherals/ledmatrix.h"
#include "../../Utilities/random.h"

MemoryMatchingState::MemoryMatchingState()
    : GameBaseState(GameState::MemoryMatching),
      ledBrightnessAdjustTimer(0),
      correctMatches(0),
      selectedLedIndex1(-1),
      selectedLedIndex2(-1),
      isGuessCorrect(false),
      colorList {
          Colors::pink,
          Colors::turquoise,
          Colors::blue,
          Colors::purple,
          Colors::green,
          Colors::red,
          Colors::orange,
          Colors::yellow,
          Colors::green,
          Colors::red,
          Colors::turquoise,
          Colors::purple,
          Colors::pink,
          Colors::blue,
          Colors::orange,
          Colors::yellow} {}

void MemoryMatchingState::enterState(GameState previousState)
{
    GameBaseState::enterState(previousState);
    shuffleLedColors();
}

void MemoryMatchingState::exitState()
{
    ledBrightnessAdjustTimer.setTargetTime(0);
    correctMatches = 0;
    selectedLedIndex1 = -1;
    selectedLedIndex2 = -1;
    isGuessCorrect = false;
    nextState = GameState::None;
}

void MemoryMatchingState::updateState()
{
    if (ledBrightnessAdjustTimer.isComplete())
        return;

    ledBrightnessAdjustTimer.updateTimer(DeviceUtility::DELTA_TIME);

    if (!ledBrightnessAdjustTimer.isComplete())
        return;

    adjustLedBrightness();

    if (correctMatches == 8)
    {
        nextState = GameState::GameOver;
    }
}

void MemoryMatchingState::onButtonPressed(int8_t buttonIndex)
{
    if (!ledBrightnessAdjustTimer.isComplete() || LEDMatrix::getLedStatus(buttonIndex))
        return;

    if (selectedLedIndex1 == -1)
    {
        selectedLedIndex1 = buttonIndex;
    }
    else
    {
        selectedLedIndex2 = buttonIndex;
        evaluateGuess();
    }

    MusicNote musicNote = selectedLedIndex2 == -1 ? MusicNote::C5 : MusicNote::D5;
    LEDMatrix::ledOn(buttonIndex);
    AudioSource::Instance().playMusicNote(musicNote, 100);
}

void MemoryMatchingState::shuffleLedColors()
{
    // Shuffle the colorList array.
    for (int i = 15; i > 0; --i)
    {
        int j = Random::range(0, 15);
        Color temp = colorList[i];
        colorList[i] = colorList[j];
        colorList[j] = temp;
    }

    // Set Led colors.
    for (int i = 0; i < 16; ++i)
    {
        LEDMatrix::setLedColor(i, colorList[i], 1);
    }
}

void MemoryMatchingState::evaluateGuess()
{
    if (LEDMatrix::getLedColor(selectedLedIndex1) == LEDMatrix::getLedColor(selectedLedIndex2))
    {
        isGuessCorrect = true;
        ledBrightnessAdjustTimer.setTargetTime(300);
    }
    else
    {
        isGuessCorrect = false;
        ledBrightnessAdjustTimer.setTargetTime(600);
    }
}

void MemoryMatchingState::adjustLedBrightness()
{
    if (isGuessCorrect)
    {
        LEDMatrix::setLedIntensity(selectedLedIndex1, .4);
        LEDMatrix::setLedIntensity(selectedLedIndex2, .4);
        correctMatches++;
    }
    else
    {
        LEDMatrix::ledOff(selectedLedIndex1);
        LEDMatrix::ledOff(selectedLedIndex2);
    }

    selectedLedIndex1 = -1;
    selectedLedIndex2 = -1;
}

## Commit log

2023-12-02 - Added a sleep feature to reduce power consumption - Return a bool from the scan button matrix funtion to reset the sleep timer. - Changed the PWM generation for audio from timer 1 to timer 3 - Fixe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
    [main.cpp]
2024-02-12 Modified the lcd class to where it can create custom characters - Created custom heart and low battery character - used hearts as the lives for simon game - Modified the audio in simon game.
2024-02-14 Changed the address of the custom heart character and low battery character
2024-02-18 - Refactored main menu and the leds class - Created a getLedIntensityFunction - Created LedOn and LedOff functions that take in an array of indexes
2024-02-21 - Created a gameproperties class that holds information about the games - Created a high score manager that can save and retrieve high scores - Added a protected currentState constant to GameBaseStat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
2024-02-23 - removed audio includes from state files and include aduio in the base state file - fixed bug with queued state being set to memory matching when the class is initialized - modified how the high sco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
    [main.cpp]
2024-02-25 - Added a 3 second countdown timer before starting the selected game on the main menu state. - Refactored the clearDisplay function in the lcd class -
2024-03-10 - Modified the the fixed update ISR to where it is triggered every 250us. - Changed teh fixedUpdateCounter to 64 to still be a fixed update of 16ms - Changed _delay_us(2) to an assembly "NOP" call. -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
    [main.cpp]
2024-03-10 - Added a color for blue to the Colors class - Updated the brightness for leds in the main menus state - Added a function to update highlighted button timer to the main menu - Added an update countdo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
2024-03-11 - Moved statemanger to the manager directory - made the sleep timer volatile - fixed issue with the colors include path in the leds header file - changed scanButtonMatrix to where it returns void ins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
2024-03-15 - Removed the clearSystemButtonStates function from the Input class - Cleared sleep button and mute button states in teh getMuteButtonDown() and getSleepButtonUp() functions
2024-03-15 - Created a fixed update class - Created a fixed event listener class - Made sleep manager and audio source singletons - Subscribed to the fixed update events
    [main.cpp]
2024-04-01 - Refactored Light Dash - Modified lcd code to work with bjt driver circuit - Updated inlude file path in audio.cpp file.
2024-06-02 - Added a speaker and mute/unmute icon characters to the lcd - Updated the main menu to not overwrite the mute icon - updated teh main cpp to where it displays the mute icon. - Adjusted button bright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
2024-06-02 - Removed sleep button code from sleep manager - Change inputs from sleep and mute to next and previous in the button class - Added code that will mute/unmute the audio if the previous and next butto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
2024-06-02 - added a boolean to check if the mute buttons are pressed or released to the audio source - added the ability to use the previous and next buttons to cycle through games in the main menu state - add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
2024-06-07 - Added another pushbutton for difficulty selection. PD7 - Modified the main menu state to where the difficulty push button increases the difficulty - Modified the audio class to where holding the di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
2024-06-16 - Removed sleep capabilities and instead sends a signal to the power controller to power down the device - Renamed sleepmanager to shutdownutility. - Renamed sleep variables and functions to reflect 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
2024-06-23 - Created a power on state - Added the power on state to the state dictionary in the state manager - Made power on state the default state in the state manager constructor - Added a PowerOn GameState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
2025-04-03 - Modified the bootloader to check for if the pin is low and return to the main program - Started the watchdog timer in the lumisquare code. - Do not reset watchdog timer if pc6 is high. Will allow u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
    [main.c, main.cpp]
2025-05-11 - Renamed audioClip functions and variables to musicNoteSequence - Modified the score manager to where it keeps track of all high scores. - Created a setHighScore function that can be used to save th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
    [main.cpp]
2025-05-19 - Replaced all timer uint16_t timer variables with the Timer class - Created the serial command manager - MOved the usart PCINT initialization to the serial command manager - Moved the FixedUpdateEve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
    [main.cpp]
2025-08-28 - Adding the kicad project to the eda directory
    [LumiSquare.kicad_pcb, LumiSquare.kicad_sch]
2025-09-02 - Connected power portion of the schmatic - added components to the pcb editor
    [LumiSquare.kicad_pcb, LumiSquare.kicad_sch]
2025-10-17 Refactor device utilities and add desktop simulation support - Abstract DeviceUtility class with pure virtual methods for cross-platform support - Add SAMD21J18Utility concrete implementation for har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
2025-10-17 - Made updates to LumiSquare pcb and schematic
    [LumiSquare.kicad_pcb, LumiSquare.kicad_sch]
2025-10-19 Abstracted more hardware logic to the device utility class - abstracted led and rng hardware logic to the device utility class - Renamed the outputs class to LEDMatrix - put the LED class in its own 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
    [ledmatrix.cpp, lightdashstate.cpp]
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2025-11-02 Adding button matrix kicad project- - Used dma to send audio usart data for samd21
    [ButtonMatrix.kicad_pcb, ButtonMatrix.kicad_sch, LumiSquare.kicad_pcb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]
2025-11-02 - Updated mesh button connections
    [ButtonMatrix.kicad_pcb]
2025-11-06 - Updated the pcb for the new 4x4 button matrix - Added support imgui and desktop support
    [ButtonMatrix.kicad_pcb, ButtonMatrix.kicad_sch]
2025-11-07 - Updates to button matrix pcb
    [ButtonMatrix.kicad_pcb]
2025-11-08 - Added m2 mounting holes to the pcb
    [ButtonMatrix.kicad_pcb, ButtonMatrix.kicad_sch]
2025-11-09 - Added headers and connected all diods
    [ButtonMatrix.kicad_pcb, ButtonMatrix.kicad_sch]
2025-11-09 - Updated PCB more
    [ButtonMatrix.kicad_pcb, ButtonMatrix.kicad_sch]
2025-11-09 - Connected led grounds
    [ButtonMatrix.kicad_pcb]
2025-11-10 - Fixed issue in my lumisquare button footrprint - Redesign teh button fill areas to better alingn witht he button mask
    [ButtonMatrix.kicad_pcb, ButtonMatrix.kicad_sch]
2025-11-10 - Fixed silk screen overlap issuess in button pcb
    [ButtonMatrix.kicad_pcb, ButtonMatrix.kicad_sch]
2025-11-10 - Completed all connections on pcb and performed design fule check
    [ButtonMatrix.kicad_pcb]
2025-11-10 - Added rgb silkscreens to label header pins.
    [ButtonMatrix.kicad_pcb]
2025-11-10 - Added more silkscreens to label switch headers
    [ButtonMatrix.kicad_pcb]
2025-11-13 - Added gerber files for button matrix - Added miniaudio to the project - Modified the desktopUtility to utilize miniaudio to play audio
    [ButtonMatrix-B_Cu.gbl, ButtonMatrix-B_Mask.gbs, ButtonMatrix-B_Paste.gbp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]
2025-11-16 - Fixed bug with not being able to close using the x button. - Removed text labels from buttons - Updated my fixedUpdatethread function to where it properly sleeps the configured time.
2026-05-23 - uploading kicad pcb changes
    [LumiSquare.kicad_pcb, LumiSquare.kicad_sch]
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2026-05-26 -Added circuity for esd on usb. - Add p chanel mosfets. - added new footprint, symbol, and step files
    [FTSH-105-01-X-DV-P-K-X.step, GT-USB-7004--3DModel-STEP-269445.STEP, LumiSquare.kicad_pcb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]
2026-05-31 Adding updateds to pcb and schematic design
    [DFR0299.step, LumiSquare.kicad_pcb, LumiSquare.kicad_sch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]
2026-06-01 Made more progress with the pcb layout
    [LumiSquare.kicad_pcb, LumiSquare.kicad_sch]
2026-06-02 Made more progress on the pcb
    [LumiSquare.kicad_pcb]
2026-06-06 Removed usb connection components and finished circuit
    [LumiSquare.kicad_pcb, LumiSquare.kicad_sch]
2026-06-07 Fixed warnings
    [LumiSquare.kicad_pcb, LumiSquare.kicad_sch]
2026-06-10 Fixed header positions
    [LumiSquare.kicad_pcb, LumiSquare.kicad_sch]
2026-06-15 Added test points
    [LumiSquare.kicad_pcb, LumiSquare.kicad_sch]
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2026-08-30 - adding readme update and files - Adding license
    [LumiSquare.kicad_pcb, back-cover.stl, face-plate.stl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]
